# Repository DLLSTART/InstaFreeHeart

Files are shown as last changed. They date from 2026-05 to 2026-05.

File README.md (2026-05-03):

# InstaFreeHeart

> 钢铁侠胸口反应堆造型 · 可佩戴 · 充电宝 + AI 摄像 + 录音日记
>
> **Mark I 圆形特斯拉款（最终方案）：Ø90 × 15 mm · 136 g · 4000 mAh · Halbach 磁吸**

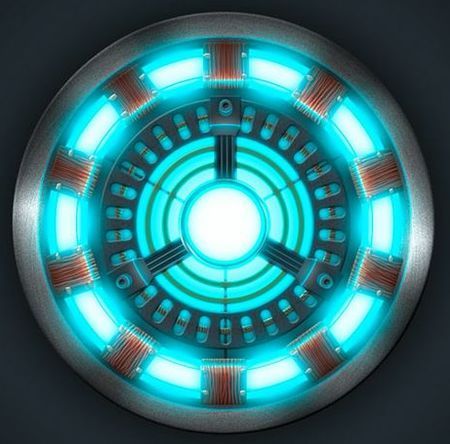
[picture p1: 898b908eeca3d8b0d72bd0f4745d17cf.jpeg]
参考造型 · Mark I 圆形


---

## 项目简介

InstaFreeHeart 是一款外形参考钢铁侠 **Mark I 圆形特斯拉反应堆** 的可穿戴智能设备
（同心 4 环 + 8 段蓝光灯柱 + 8 颗铜线圈 + Y 字三支撑）。
功能源自 [`userstory/userstory.md`](userstory/userstory.md)，从用户故事拆解出硬件，
逐步给出选型、引脚、电源拓扑、SKiDL 网表与 3D 模型。

## 整机参数

| 项 | 数值 |
|----|---|
| 外形 | 圆盘 Ø90 × 15 mm |
| 重量 | 136 g（含电池 + 散热 + 降噪辅件） |
| 电池 | 4000 mAh / 14.8 Wh（2× 2000 mAh 软包并联，DW01A + 8205A 保护） |
| 充手机能力 | iPhone 充至 ~65%（一次） |
| 续航（纯日记模式） | 5.3–7.1 天连续工作 |
| 续航（高强度模式） | 9.8–13 h 连续工作 |
| 续航（待机/Deep Sleep） | 6–8 个月 |
| 磁吸 | 中央 N52 Φ22×4 + 4× Φ8×2 周边（Halbach-like） |
| 贴衣拉力 | ~ 2.4 kg（安全系数 2.2×） |
| 后壳贴肤 | 0.5 mm 硅胶垫，μ ≈ 0.6 |
| 灯环 | 16 颗 WS2812B-2020（外圈 8 颗 Ø35 mm + 内圈 8 颗 Ø12 mm 双同心环） |
| 装饰件 | 8 颗 SLA 打印铜色线圈 |
| 皮肤接触温度 | 正常 38 ℃ / 最坏 40.7 ℃（限功率后） |
| BOM 总价 | ≈ ¥133 / 台 |

## 核心能力

| # | 能力 | 关键硬件 |
|---|---|---|
| 1 | USB-C 充电宝 (5V/1A 输出) | IP5306 + 锂聚电池 + USB-C |
| 2 | 磁吸佩戴 | N52 钕磁铁 + 钢质吸片 |
| 3 | 钢铁侠环形发光 | 16 颗 WS2812B-2020 |
| 4 | **HDR 夜景拍摄 → AI 日记** | OV5640 (硬件 HDR) + Mertens 软件融合 + ESP32-S3 |
| 5 | WiFi/BLE 上传 | ESP32-S3 内置射频 |
| 6 | 本地 LLM + 离散图片合成日记 | ESP32-S3 (8 MB PSRAM) + microSD |
| 7 | **双麦差分降噪 + 1s 阈值录音存档** | 双 INMP441 + Gore-Tex 防风罩 + WebRTC NSx |
| 8 | **散热闭环温控** | ADS1115 + 3 NTC + 石墨烯膜 + 导热硅胶垫 |
| 9 | **高效电源** | SY8088 Buck (3V3 路径 η=92%) |

## 仓库结构

```
InstaFreeHeart/
├── README.md
├── 898b908eeca3d8b0d72bd0f4745d17cf.jpeg        参考造型（Mark I 圆形）
│
├── userstory/
│   └── userstory.md                              用户需求
│
├── hardware/                                     电气设计
│   ├── requirements.md                           用户故事 → 硬件能力 拆解
│   ├── bom.md                                    BOM（含嘉立创/LCSC 料号）
│   ├── pin_mapping.md                            ESP32-S3 GPIO 详细分配
│   ├── power_tree.md                             电源拓扑、充放策略、BMS
│   ├── schematic.py                              SKiDL 主原理图
│   ├── lib/parts.py                              SKiDL 自定义零件模板
│   └── output/
│       ├── instafreeheart.net                    KiCad 兼容网表
│       └── instafreeheart.xml                    KiCad 兼容 XML
│
├── mechanical/                                   结构设计
│   ├── 3d_design.md                              3D 建模思路
│   ├── thermal.md                                散热设计
│   ├── power_budget.md                           功耗预算与续航
│   └── openscad/
│       ├── parameters.scad                       全局尺寸（改一处即改全机）
│       ├── instafreeheart.scad                   主装配文件（OpenSCAD F5/F6）
│       ├── preview.py                            Python 多视图预览
│       ├── thermal_preview.py                    散热可视化
│       ├── power_preview.py                      功耗可视化
│       ├── README.md                             OpenSCAD 安装与渲染指南
│       └── out/                                  全部生成的预览/分析图
│
└── firmware/                                     固件 demo（ESP-IDF）
    ├── README.md
    ├── thermal_guard.c                           散热守卫（NTC + 状态机）
    ├── diary_mode.c                              Light Sleep 调度器
    ├── hdr_pipeline.c                            软件 HDR (Mertens fusion)
    ├── hdr_pipeline.md                           HDR pipeline 文档
    └── audio_denoise.md                          双麦差分 + WebRTC NSx 集成
```

## 主要硬件选型

| 子系统 | 方案 | 嘉立创料号 |
|---|---|---|
| 主控 | ESP32-S3-WROOM-1-N16R8 | C2913204 |
| 摄像头 | OV5640 (DVP, 5MP, 硬件 HDR) | C44391 |
| 麦克风 | INMP441 ×2 (I²S MEMS, 立体声差分) | C126667 |
| 充放管理 | IP5306 | C71064 |
| 电量计 | CW2015 | C113566 |
| 3V3 主电源 | **SY8088** (1.5 MHz Buck, η=92%) | C36420 |
| 温度采集 | ADS1115 + 3× NTC 10K B3950 | C37593 + C58436 |
| LED | WS2812B-2020 × 16 | C2761815 |
| TF 卡座 | microSD Push-Push | C701637 |
| USB-C | TYPE-C-31-M-12 | C165948 |
| ESD | USBLC6-2SC6 | C7519 |

详见 [`hardware/bom.md`](hardware/bom.md)。

## 工作流

```
┌─────────────┐     ┌────────────┐     ┌────────────────┐     ┌──────────────┐
│ ① 拆解需求   │ ──> │ ② 硬件选型  │ ──> │ ③ SKiDL 描述电路 │ ──> │ ④ ERC + 网表 │
│ requirements│     │ bom.md     │     │ schematic.py   │     │ output/*.net │
└─────────────┘     └────────────┘     └────────────────┘     └──────┬───────┘
                                                                      │
                                                                      ▼
       ┌──────────────┐     ┌──────────────┐     ┌──────────────┐
       │ ⑦ 固件实现    │ <── │ ⑥ 散热/功耗  │ <── │ ⑤ 机械建模    │
       │ firmware/    │     │ thermal+pwr  │     │ openscad/    │
       └──────────────┘     └──────────────┘     └──────────────┘
```

## 运行 SKiDL

```bash
pip3 install --user skidl
cd InstaFreeHeart
PYTHONPATH=hardware python3 hardware/schematic.py
```

输出：`hardware/output/instafreeheart.net` + `.xml`，**ERC: 0 errors / 0 warnings**。

## 生成预览图

```bash
cd mechanical/openscad
python3 preview.py            # 5 张 3D 模型预览图
python3 thermal_preview.py    # 散热设计可视化
python3 power_preview.py      # 功耗预算 + 续航可视化
```

## 下一步

1. 在 KiCad 中导入 `hardware/output/instafreeheart.net` → 双面 1.6 mm PCB → 嘉立创下单
2. 用 OpenSCAD 渲染 `mechanical/openscad/instafreeheart.scad` → STL → PETG 0.2 mm 层高 3D 打印
3. 把 `firmware/*.c` 加入 ESP-IDF 工程，按 [`firmware/README.md`](firmware/README.md) 集成

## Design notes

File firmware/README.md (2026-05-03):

# InstaFreeHeart · 固件 (ESP-IDF v5.x)

> 该目录暂时只放散热守卫 demo（`thermal_guard.c`）；后续会陆续补充
> `app_main`、`camera_task`、`ai_task`、`led_ring_task`、`mic_task`、
> `power_manager` 等任务模块。

## 目录约定

```
firmware/
├── README.md                    ← 本文件
├── thermal_guard.c              ← 散热守卫（NTC × 3 + 4 阈值降功耗）
├── thermal_guard.h              (建议生成)
└── (后续) main/                 ← ESP-IDF 工程入口
    components/
        thermal_guard/
        camera_task/
        ai_task/
        ...
```

## thermal_guard.c 集成步骤

### 1. 拷贝到组件目录

```bash
mkdir -p components/thermal_guard
cp firmware/thermal_guard.c components/thermal_guard/
```

`components/thermal_guard/CMakeLists.txt`:

```cmake
idf_component_register(
    SRCS         "thermal_guard.c"
    INCLUDE_DIRS "."
    REQUIRES     driver freertos esp_event log
)
```

### 2. 在 `app_main()` 中初始化

```c
#include "driver/i2c_master.h"
#include "thermal_guard.h"

void app_main(void) {
    /* 1) 初始化共享 I2C 总线（OV5640 SCCB / CW2015 / ADS1115 共用）         */
    i2c_master_bus_config_t bus_cfg = {
        .i2c_port = I2C_NUM_0,
        .sda_io_num = 4,
        .scl_io_num = 5,
        .clk_source = I2C_CLK_SRC_DEFAULT,
        .glitch_ignore_cnt = 7,
        .flags.enable_internal_pullup = false,  // 已外部 4.7K 上拉
    };
    i2c_master_bus_handle_t bus;
    ESP_ERROR_CHECK(i2c_new_master_bus(&bus_cfg, &bus));

    /* 2) 启动散热守卫（自动启动后台 1 Hz 任务）                              */
    ESP_ERROR_CHECK(thermal_guard_init(bus));

    /* 3) 其它任务通过 thermal_allows() 协作                                  */
    while (1) {
        if (thermal_allows(BIT_ALLOW_AI)) {
            run_ai_inference();
        }
        vTaskDelay(pdMS_TO_TICKS(50));
    }
}
```

### 3. 看日志

正常运行（25 ℃）：

```
I (1042) thermal: T_BAT=26.3  T_PMU=27.1  T_MCU=29.5  state=OK
I (2043) thermal: T_BAT=26.4  T_PMU=27.5  T_MCU=29.8  state=OK
```

进入 WARM（>38 ℃）：

```
W (87654) thermal: T_BAT=37.1  T_PMU=38.4  T_MCU=37.9  →  OK → WARM
I (88654) thermal: T_BAT=37.2  T_PMU=38.6  T_MCU=38.0  state=WARM
```

紧急关机（>45 ℃）：

```
W (123456) thermal: T_BAT=44.0  T_PMU=46.2  T_MCU=44.8  →  CRIT → PANIC
E (123456) thermal: PANIC! Entering deep-sleep to protect user.
```

## 阈值（与 `mechanical/thermal.md` 一致）

| 状态 | 触发温度 | 允许子系统 |
|---|---|---|
| OK | T < 38 ℃ | 全部允许 |
| WARM | T ≥ 38 ℃ | 灯环亮度减半，充电限到 0.5 C |
| HOT | T ≥ 41 ℃ | 暂停 AI、WiFi 仅 BLE |
| CRIT | T ≥ 43 ℃ | 仅充电不输出，禁用摄像头 |
| PANIC | T ≥ 45 ℃ | 紧急关机（deep-sleep） |

降级触发增加 1.5 ℃ 滞回，避免在阈值附近抖动。

## NTC 校准

NTC 默认参数：MF52E 10 kΩ B25/50 = 3950，± 1%。
若改用其它型号（B 值不同），修改 `thermal_guard.c` 顶部宏：

```c
#define NTC_R0      10000.0f     // 25 ℃ 阻值
#define NTC_T0      298.15f      // 25 ℃ 开尔文
#define NTC_BETA    3950.0f      // β 值
#define NTC_PULLUP  10000.0f     // 上拉电阻
```

## 烧录 / 调试

```bash
idf.py set-target esp32s3
idf.py menuconfig            # 选 PSRAM = Octal, Flash = 16MB
idf.py build flash monitor
```

预期监控输出每秒一行 `state=OK/WARM/HOT/CRIT/PANIC`，状态切换时
另有 `WARN` 行打印温度详细值。

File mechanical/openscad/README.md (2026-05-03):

# InstaFreeHeart · OpenSCAD 3D 模型

参数化的 3D 模型，配合 `mechanical/3d_design.md` 中的设计思路。

## 顶视图预览

InstaFreeHeart 顶视图

> 上图由 `preview.py` 用 matplotlib 直接从 `parameters.scad` 读参数生成，
> 无需 OpenSCAD 也能先看到设计效果。
>
> 调整 `parameters.scad` 后，重跑 `python3 preview.py` 即可刷新这张图。

## 文件清单

| 文件 | 作用 |
|---|---|
| `parameters.scad` | 全局参数（尺寸、颜色、爆炸系数）— 调整这里就能改全机 |
| `instafreeheart.scad` | 全部模块定义 + 总装配（main entry，OpenSCAD 打开此文件） |
| `preview.py` | 用 matplotlib 把外形/磁铁/灯环画成顶视图 PNG/SVG（不需要 OpenSCAD） |
| `out/preview.png` `out/preview.svg` | preview.py 的输出 |
| `out/*.stl`（OpenSCAD F6 后生成） | 3D 打印用 STL |
| `README.md` | 当前文件 |

## 安装 OpenSCAD（macOS）

任选其一：

```bash
# 1. 官网安装包（推荐）
open https://openscad.org/downloads.html
# 下载 OpenSCAD-2021.01.dmg → 拖到 /Applications/

# 2. Homebrew Cask（如果 brew 可用）
brew install --cask openscad

# 3. 启用 CLI（命令行渲染需要）
echo 'export PATH="/Applications/OpenSCAD.app/Contents/MacOS:$PATH"' >> ~/.zshrc
source ~/.zshrc
openscad --version
```

## 快速预览

```bash
# 用 OpenSCAD 桌面应用打开
open -a OpenSCAD instafreeheart.scad

# 在 OpenSCAD 中：
#   F5  → 快速预览
#   F6  → 完整渲染（可导出 STL）
#   File → Export → Export as STL...
```

## 命令行批量渲染

```bash
# 渲染装配体的等轴侧视图
openscad -o out/assembly.png \
  --imgsize 1600,1200 \
  --camera 0,0,0,55,0,25,250 \
  --colorscheme=Tomorrow \
  instafreeheart.scad

# 导出整机 STL（用于 3D 打印）
openscad -o out/instafreeheart_assembly.stl instafreeheart.scad
```

## 单件导出（每个零件单独打印）

编辑 `instafreeheart.scad` 文件末尾的「单件导出」一节：

```scad
// ----- 把这一行注释掉 -----
// assembly();

// ----- 启用要导出的零件 -----
front_shell();        // 前壳（SLA / FDM 高精度）
// crown();           // 顶冠
// back_shell();      // 后壳（FDM PETG）
// diffuser();        // 扩散板（CNC PMMA）
// led_ring();        // 灯环 PCB（仅可视化，实际下嘉立创）
// main_pcb();        // 主控 PCB（仅可视化）
// silicon_pad();     // 硅胶垫（CNC 切割）
```

然后：`F6 → File → Export → STL`。

## 切换爆炸视图

修改 `parameters.scad`：

```scad
EXPLODE = 0;     // 0 = 装配体（默认）
EXPLODE = 8;     // 中等爆炸
EXPLODE = 18;    // 完全分散，便于看每个零件
```

## 设计要点速览（对应 `mechanical/3d_design.md`）

```
Z+ (朝外)
   ┌──────────────┐
   │  ① 前壳       │  色: 银  · linear_extrude(diamond) - grid - hex_pattern
   │  + 顶冠       │  色: 金
   ├──────────────┤
   │  ② 扩散板     │  色: 半透蓝
   │  ③ LED 灯环   │  16 颗 ws2812B 圆周等分
   │  ④ 主控 PCB   │  色: 嘉立创深绿，顶面有摄像头模组
   │  ⑤ 双电池     │  左右对称，中间留 PCB 元件区
   │  ⑥ 后壳       │  色: 黑，含 5 颗磁铁卡位 + USB-C 开槽 + 透气孔
   │  ⑦ 硅胶垫     │  色: 半透黑，按外形冲切
   └──────────────┘
Z- (贴胸)
```

## 已实现的几何特征

- ✅ 钻石外形（17 顶点 polygon，可视化贴近参考图）
- ✅ 内部主十字 + 4 条对角支撑格栅
- ✅ 蜂窝纹理凹刻（hex pattern，0.6 mm 深）
- ✅ 中央 I 字形扩散区（参考图蓝光形状）
- ✅ LED 灯环 16 颗等距分布 + 中央摄像头开窗
- ✅ Halbach 磁吸阵列（中央 Φ22 + 4× Φ8 周边）
- ✅ USB-C 底尖侧方开槽
- ✅ 后壳透气孔阵列（避开磁铁正下方）
- ✅ 中央磁铁背面补强环
- ✅ 全部模块独立 module，可单独导出 STL

## 常见调整示例

```scad
// 改电池方案为 4000 mAh（方案 B）
BATTERY_T = 8.0;        // 电池厚度 +2mm
TOTAL_THK = 16;         // 整机厚度 +2mm

// 改磁吸为单中心磁铁（方案 C）
MAG_E_R = 0;           // 周边磁铁半径置零（重叠到中心，等于不存在）
// 或者修改 magnet_array() 删除 for 循环

// 调整钻石形比例（更扁/更长）
BODY_W = 100;           // 横向 +10
BODY_H = 60;            // 纵向 -5
```

## 后续可加的细节（按需）

- [ ] 主板上的 USB-C 沉板让位（PCB 边缘倒角）
- [ ] 顶冠的金色铆钉细节（小圆柱浮雕）
- [ ] 扩散板边缘抛光斜角（45° chamfer）
- [ ] 后壳 R200 球面贴胸曲率（用 `sphere(r=200)` intersection）
- [ ] 螺丝柱（M2 沉头螺丝定位）

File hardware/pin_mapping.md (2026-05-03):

# InstaFreeHeart 引脚分配

> 主控：ESP32-S3-WROOM-1-N16R8（44-pin SMD 模组）
> 模组内部已占用 GPIO 33~37（Octal PSRAM/Flash），对外不可用。
> Strapping pin（避免做普通 IO）：GPIO0, 3, 45, 46
> USB-OTG 内部走 GPIO19/20（如使用原生 USB）。

## 引脚分配表

| GPIO | 方向 | 连接 | 子系统 | 说明 |
|-----:|---|---|---|---|
| IO0  | I | SW1 (BOOT) + 10 kΩ 上拉 | 系统 | 兼下载启动 |
| IO1  | — | NC | — | 预留 |
| IO2  | I | INMP441 ×2 共享 SD（双麦立体声 LR 时序） | 麦克风 I²S | 主/副麦共用一根 SD 线，按 LR 通道分时复用 |
| IO3  | — | NC（strapping，建议悬空或外部上拉） | — | 慎用 |
| IO4  | I/O  | I²C SDA (CW2015 + OV5640 SCCB + ADS1115 共用) | I²C0 | 4.7 kΩ 上拉到 3V3 |
| IO5  | O | I²C SCL (CW2015 + OV5640 SCCB + ADS1115 共用) | I²C0 | 4.7 kΩ 上拉到 3V3 |
| IO6  | I | OV5640 VSYNC | 摄像头 DVP | |
| IO7  | I | OV5640 HREF | 摄像头 DVP | |
| IO8  | I | OV5640 D2 | 摄像头 DVP | |
| IO9  | I | OV5640 D1 | 摄像头 DVP | |
| IO10 | I | OV5640 D3 | 摄像头 DVP | |
| IO11 | I | OV5640 D0 | 摄像头 DVP | |
| IO12 | I | OV5640 D4 | 摄像头 DVP | |
| IO13 | I | OV5640 PCLK | 摄像头 DVP | |
| IO14 | I | SW2 (USER) | 按键 | 模式切换 / 唤醒 |
| IO15 | O | OV5640 XCLK | 摄像头 DVP | LEDC PWM 20 MHz |
| IO16 | I | OV5640 D7 | 摄像头 DVP | |
| IO17 | I | OV5640 D6 | 摄像头 DVP | |
| IO18 | I | OV5640 D5 | 摄像头 DVP | |
| IO19 | I/O  | USB-C D- | USB-OTG | 原生 USB Serial/JTAG |
| IO20 | I/O  | USB-C D+ | USB-OTG | 原生 USB Serial/JTAG |
| IO21 | O | OV5640 PWDN | 摄像头 DVP | 高电平断电省流 |
| IO38 | O | WS2812B DIN | 灯环 | RMT/SPI 驱动 |
| IO39 | O | TF_CS | microSD SPI | CS |
| IO40 | O | TF_SCK | microSD SPI | |
| IO41 | O | INMP441 WS (LRCLK) | 麦克风 I²S | |
| IO42 | O | INMP441 SCK (BCLK) | 麦克风 I²S | |
| IO43 | I/O  | UART0 TX (调试串口) | 调试 | 默认 U0TXD |
| IO44 | I/O  | UART0 RX (调试串口) | 调试 | 默认 U0RXD |
| IO45 | I | IP5306 KEY (开机/状态检测) | 电源 | strapping，外部需弱上拉 |
| IO46 | O | LED_PWR (状态绿灯) | 状态 | strapping，仅做 OUT 上电后 |
| IO47 | I | TF_MISO | microSD SPI | |
| IO48 | O | TF_MOSI | microSD SPI | |

## 总线占用一览

- **DVP（摄像头并行总线）**：IO6,7,8,9,10,11,12,13,15,16,17,18,21（含 XCLK/PWDN）
- **I²C0**：IO4(SDA) / IO5(SCL) — 挂载：
  - OV5640 SCCB（地址 0x3C）
  - CW2015（地址 0xC4 / 0x62 — 1S 锂电库仑计）
  - ADS1115（地址 0x48 — 散热三 NTC 温度采集，AIN0=电池 / AIN1=PMU / AIN2=MCU）
- **I²S0**：IO2(SD) / IO41(WS) / IO42(SCK) — 双 INMP441 立体声（MIC_A=L 通道, MIC_B=R 通道，共用 SD 线）
- **SPI3 (HSPI)**：IO39(CS) / IO40(SCK) / IO47(MISO) / IO48(MOSI) → microSD
- **RMT**：IO38 → WS2812 DIN
- **USB-OTG**：IO19(D-) / IO20(D+) → USB-C 数据
- **UART0**：IO43(TX) / IO44(RX) → 调试

## 已知冲突 / 注意事项

1. **I²C0 三机共用**：OV5640 SCCB (0x3C) + CW2015 (0x62) + ADS1115 (0x48)，地址互不冲突。
2. **IO45/46 是 strapping pin**：上电时电平会影响 boot mode。IO45 接 IP5306 KEY 用「OD + 弱上拉」；IO46 仅做输出（默认 LOW，不影响 boot）。
3. **PSRAM Octal 占用 IO33~37**：模组内部连接，PCB 上不要外接这些网络。
4. **摄像头与 microSD 不复用 IO**：刻意避免 ESP32-CAM 老板上 SDIO 与 DVP 抢 IO 的问题。
5. **DVP 数据 D0~D7 使用 ESP32-S3 GPIO 矩阵**：可任意映射，编号顺序在 `esp_camera_config_t` 中调整即可。
6. **散热温度采集走外部 ADS1115（不占 GPIO）**：ESP32-S3 的 ADC1（IO1~10）几乎被 I2C/I2S/DVP 占满，且 ADC2（IO11~20）在 WiFi 工作时被禁用。把 3 颗 NTC 挂到 ADS1115 后清爽集成，详见 [`../mechanical/thermal.md`](../mechanical/thermal.md)。

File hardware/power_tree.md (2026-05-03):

# InstaFreeHeart 电源拓扑（双电池并联 · Buck 直供 3V3）

> 详见功耗预算：[`mechanical/power_budget.md`](../mechanical/power_budget.md)

## 1. 电源树（双路供电）

```
                ┌───────────────────────┐
   USB-C (5V) ──┤ VBUS         IP5306   │
                │  (输入 1A 充电)         │
                │                        │
                │  BAT  ◄───── 4.2V CC/CV│
                └─────┬───────────┬─────┘
                      │           │
              ┌───────▼─────┐     │ KEY
              │ 锂电保护板    │     │ (按键检测/工作灯)
              │ DW01A+8205A │     │
              └───────┬─────┘     │
                      │           │
              ┌───────▼─────┐     │
              │  电池 1S2P   │     │
              │ 2× 2000 mAh │     │
              │ = 4000 mAh   │     │
              └─┬───────┬───┘     │
                │       │         │
                │       │  ┌──────▼─────────┐
                │       ├──┤ IP5306 BOOST 5V│──── VOUT_5V ──── USB-C(对外，给手机充)
                │       │  └────────┬───────┘                  │
                │       │           │                          └─→ WS2812B 灯环 (NMOS 切)
                │       │           │
                │       │  *5V 仅在充手机/驱动 5V 灯环时使用，平时 IP5306 静态 1.85 mW*
                │       │
                │       │   ┌────────────────────────┐
                │       └───┤   SY8088 Buck          │──   3.3V ── ESP32-S3 / OV5640 /
                │           │   3.7V → 3.3V/1A       │             INMP441 ×2 / TF / CW2015 /
                │           │   1.5 MHz, η=92%       │             ADS1115
                │           │   2.7~6.5V 输入        │
                │           └────────────────────────┘
                │
                └─── CW2015 (BAT+) ── I²C(SDA/SCL) → ESP32
                          电量计 / SoC 估计 + 库仑积分

3V3 由 BAT 直接通过 Buck 供电（η=92%）；IP5306 仅在 USB-C 充电或对外输出 5V 时启用升压。
```

## 2. 电源域汇总

| 电源域 | 电压 | 来源 | 典型电流 | 峰值电流 | 关断方式 |
|---|---|---|---|---|---|
| VBUS | 5 V  | USB-C 输入 | 0~1.5 A | 2 A | USB 拔出 |
| BAT | 3.0~4.2 V | 锂电芯 1S2P (4000 mAh) | — | 充 1.5A / 放 3 A | DW01A 触发 |
| VOUT_5V | 5 V | IP5306 升压（仅充手机/灯环时启用） | 0~1 A | 2.1 A | IP5306 KEY 双击 |
| VSYS_3V3 | 3.3 V | SY8088 Buck (从 BAT 直供) | 150 mA (含摄像头) | 600 mA | EN=GND |
| VCAM | 2.8 V (内部) | OV5640 内部 LDO | 100 mA | 150 mA | OV5640 PWDN |

## 3. 关键电源元件计算

### 3.1 IP5306 升压电感
- 输入：BAT 3.7 V，输出 5 V/1 A，效率 ≈ 90%。
- 推荐 2.2 µH，饱和电流 ≥ 3 A，DCR ≤ 30 mΩ。

### 3.2 SY8088 Buck 外围
- **L_BUCK** = 2.2 µH @ Isat ≥ 2 A，DCR ≤ 50 mΩ（如 SLW2520 系列）
- **C_in**  = 22 µF / 6.3V 0805 MLCC，紧贴 VIN 引脚
- **C_out** = 10 µF / 6.3V 0805 MLCC，紧贴 VOUT
- **R_FB1** = 1 MΩ（FB 上拉），**R_FB2** = 220 kΩ（FB 下拉）→ V_out = 3.32 V
- **占板面积**：约 4×3 mm（含 SOT-23-5 + L + C_in + C_out + 2× 0402 R）

### 3.3 摄像头瞬态
- OV5640 进入工作时电流瞬升 100→150 mA，3.3V 轨需 ≥10 µF 局部去耦放在距离 OV5640 5 mm 内。
- SY8088 在 1.5 MHz 开关频率下瞬态响应 < 50 µs，无需额外大电容。

### 3.4 灯环峰值电流
- WS2812B-2020 单颗满白 ≈ 30 mA；16 颗满白 ≈ 480 mA。
- 经 NMOS 开关从 VOUT_5V 取电；软件层面限亮度（默认 30%）使峰值 ≤ 200 mA。

## 4. 锂电池保护板（DW01A + 8205A）

```
    BAT_CELL+ ──┬─────────────────────── B+ (BAT 引出，进 IP5306)
                │
              ┌─▼─┐
              │   │  DW01A
              │ V │   - VDD: BAT_CELL+
              │ D │   - VSS: BAT_CELL-（电池负极）
              │ D │   - VM:  保护板 P-，监测 P- 端电压
              │   │   - OD:  放电控制 → 8205A G1
              │ V │   - OC:  充电控制 → 8205A G2
              │ M │   - TD:  延时电容（0.1µF 到 GND）
              └─┬─┘
                │
            8205A 双 NMOS（DPAK SOT-23-6）
            ┌─────────────┐
            │  D1 D2      │ ← 漏极并联
            │  G1     G2  │ ← 分别由 DW01A OD/OC 驱动
            │  S1     S2  │ ← 串联在电池负极回路
            └──┬───────┬──┘
               │       │
       BAT_CELL-       P-（板对外的 BAT- 节点）
                       │
                   连接 IP5306 GND / 系统 GND
```

保护阈值（DW01A 默认）：
- 过充电压：4.30 V ± 0.05 V
- 过放电压：2.40 V ± 0.10 V
- 过流保护：电流·内阻 > 0.15 V 触发（约 3 A 起跳）
- 短路保护：< 10 µs 切断

> 双电池并联时，两颗电池正极、负极分别先短接，再共同接保护板的
> CELL+/CELL−，由 DW01A 监控总组电压（不做 cell-balancing，因为同型号同批次
> 的并联电池容量自然均衡，无 cell-imbalance 风险）。

## 5. 充放策略

| 状态 | IP5306 行为 | ESP32 行为 |
|---|---|---|
| 仅插 USB-C，未接负载 | 给电池充电 | 正常工作，灯环显示充电进度（呼吸） |
| 插 USB-C + 接手机 | 给电池充电 + 给手机供电（旁路） | 正常工作，灯环显示满环 |
| 拔 USB-C，接手机 | 电池经 BOOST 给手机供电 | 正常工作 + 监控 SoC，<10% 时关断输出 |
| 仅电池供电，无外设 | 待机 / 30 s 后自动关断 BOOST | 软件唤醒 IP5306 KEY 拉低重启 |
| SoC < 5% | 强制关断 BOOST | 软件保存 NVRAM 后深度睡眠 |

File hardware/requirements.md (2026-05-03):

# InstaFreeHeart 硬件需求拆解

> 输入：`userstory/userstory.md`
> 输出：功能 → 硬件子系统 → 关键技术指标的映射

## 1. 用户故事到硬件能力的拆解

| US# | 用户故事（摘要） | 衍生的硬件能力 | 关键指标 |
|----|---|---|---|
| US1 | USB 给手机充电（充电宝） | USB-C 母座、5V 升压、锂电充放管理 | Vout = 5V / ≥1A |
| US2 | 磁吸佩戴在胸前 | 圆形钕磁铁 + 钢质吸片（机械件，无电气） | 吸力 ≥ 2 kg |
| US3 | 工作时亮起钢铁侠环形灯 | 可寻址 RGB LED 环、PWM/RMT 驱动 | 16 颗 WS2812B-2020 |
| US4 | 中央摄像头间断拍照 → 上传云端 AI | DVP 摄像头 + WiFi + 软件 HDR | 500W 像素，HDR ≥ 120 dB |
| US5 | 网络通信能力 | WiFi 2.4GHz + BLE 5.0 | 吞吐 ≥ 1 Mbps |
| US6 | 本地大模型处理图片 → 生成日记 | AI 加速指令、≥8 MB PSRAM、≥16 MB Flash、microSD 缓存 | 跑 ESP-DL / TFLite Micro |
| US7 | 录音 ≥1s 触发保存 | 双 I2S MEMS 数字麦克风（差分降噪） | 16 kHz, 24 bit，立体声 |
| —  | 散热安全（不烫伤皮肤） | NTC 温度采集 + 闭环温控 + 石墨烯均温 | 皮肤温度 ≤ 41 ℃ |
| —  | 续航 10–12 h（高强度模式） | 高效 buck + Light Sleep 调度 | 4000 mAh + η=92% |

## 2. 子系统划分

```
┌────────────────────────────────────────────────────────────────────────┐
│                         InstaFreeHeart 系统                            │
├──────────────┬─────────────────┬──────────────────┬────────────────────┤
│   电源子系统    │    主控子系统      │    感知子系统       │   人机交互子系统       │
├──────────────┼─────────────────┼──────────────────┼────────────────────┤
│ • USB-C 母座   │ • ESP32-S3-     │ • OV5640 摄像头   │ • WS2812B 环形灯    │
│ • IP5306 充放管 │   WROOM-1-N16R8 │   (DVP + 硬件 HDR)│   ×16 颗           │
│ • SY8088 Buck  │ • 16 MB Flash   │ • INMP441 ×2 立体 │ • 状态 LED         │
│   (3V3 η=92%)  │ • 8 MB PSRAM    │   声差分降噪麦      │ • 按键 ×2 (BOOT、  │
│ • CW2015 电量计 │ • WiFi + BT5    │ • microSD TF 卡座 │   USER)            │
│ • DW01A+8205A  │ • Vector AI     │ • ADS1115 +       │                   │
│   保护板        │   instr.        │   3 NTC 温控      │                   │
│ • 2× 2000 mAh  │                 │                  │                   │
│   软包并联       │                 │                  │                   │
└──────────────┴─────────────────┴──────────────────┴────────────────────┘
```

## 3. 数据/能量流

```
[手机/外设] <─USB-C─> [IP5306 升压 5V]   ┐
                          ▲              │ 充电
                          │ 充电状态/电量   ▼
                          │       [BAT 4000 mAh] ──┐
                          │                       │
                          │       [SY8088 Buck]──> 3V3 ──> [ESP32-S3]
                          │       (η=92%)               │   │     │
                          │                             │   │     │
                          ▼                       I2S/I2C/DVP 各路总线
                     [USB-C 5V 输出]                    │
                     (给手机充电)              ┌────────┼─────────┐
                                              ▼        ▼         ▼
                                     [INMP441 ×2] [I²C 设备群] [OV5640]
                                                    │              │
                                                    │              │ 抓帧
                              CW2015 + ADS1115 + OV5640 SCCB   [PSRAM 帧缓存]
                                                                   │
                                                       [HDR 融合 + ESP-DL 推理]
                                                                   │
                                                       [microSD 缓存图片/语音]
                                                                   │
                                                       [WiFi → 云端日记合成]
```

## 4. 设计选型决策记录

| 决策点 | 选择 | 原因 |
|---|---|---|
| 主控 | ESP32-S3-WROOM-1-N16R8 | 单芯片整合 WiFi/BT/AI 加速，DVP+I²S 同时可用，固件生态成熟（esp-camera / esp-dl） |
| 摄像头 | OV5640 (DVP, 5MP) | 500W 像素 + 硬件 line-interleaved HDR，esp32-camera 已支持，夜景日记关键 |
| 麦克风 | INMP441 ×2 | I²S 数字接口免 ADC；双麦立体声差分降噪 + 防风罩 |
| 充电管理 | IP5306 | 集成充电+升压+LED 指示+按键检测，BOM 极简 |
| 电量计 | CW2015 | 精度优于分压方案，国产成本低，I²C |
| 3V3 主电源 | SY8088 Buck (1.5 MHz) | 直接 BAT→3V3，η=92%（vs LDO 路径 56%），续航 +66% |
| 电池保护 | DW01A + 8205A | 国产标配方案，过充/过放/过流/短路全保护 |
| 灯环 | WS2812B-2020 ×16 | 单线通信节省 IO，2020 封装紧凑适合环形排布 |
| 电池 | 2× 3.7V 2000 mAh 软包并联 | 总 4000 mAh / 14.8 Wh，厚 7 mm 可装入 15 mm 整机厚度 |
| 接口 | USB-C | 双向 5V，正反插，统一现代接口 |
| 散热温控 | ADS1115 + 3 NTC | 不占 GPIO；4 通道 16-bit 精度足够 |
| 散热增强 | 25 µm 石墨烯膜 + 0.5 mm TIM | 横向均温（k=1500） + 纵向导热到后壳 |

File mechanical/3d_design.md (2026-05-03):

# InstaFreeHeart 3D 建模思路（Mark I 圆形特斯拉款）

> 参考图：`../898b908eeca3d8b0d72bd0f4745d17cf.jpeg`
> 目标外形：钢铁侠《钢铁侠 1》Mark I 圆形特斯拉反应堆（同心 4 环 + 8 铜线圈 + Y 字三支撑）。
> 建模软件：**OpenSCAD（已实现，见 `openscad/`）**。
>
> OpenSCAD 参数化模型：
> - `openscad/parameters.scad` — 全局尺寸（修改这一处就改全机）
> - `openscad/instafreeheart.scad` — 圆盘 + 4 同心环 + 8 灯柱 + 8 铜线圈 + Y 三支撑 + 磁吸 + USB-C 完整装配
> - `openscad/preview.py` — 不装 OpenSCAD 也能先生成多视图 PNG（见 `openscad/out/preview_overview.png`）

## 0. 整机参数

| 项 | 数值 |
|----|---|
| 外形 | 圆盘 Ø90 × 15 mm |
| 重量 | 136 g |
| 电池 | 双 2000 mAh 并联 = 4000 mAh / 14.8 Wh |
| 磁吸 | 中央 N52 Φ22×4 + 4× N52 Φ8×2 周边（Halbach-like） |
| 后壳贴肤 | 0.5 mm 硅胶垫，提升摩擦 + 缓冲 |
| 灯环 | 16 颗 WS2812B-2020，双同心环（外圈 8 + 内圈 8） |
| 装饰件 | 8 颗 SLA 打印铜线圈（喷铜色漆，Φ8×2.5 mm） |
| 摄像头 | OV5640 居中，光圈窗 Ø12 mm |

## 1. 主体形态分析（Mark I 圆形特斯拉款）

参考图给出的核心特征：

| 特征 | 描述 | 几何要点 |
|---|---|---|
| 整体外形 | 完美圆盘 | Ø90 mm，厚 15 mm |
| 第 1 环（外） | 银色金属外圈 | OD90 / ID80，宽 5 mm |
| 第 2 环 | **8 段蓝光灯柱** + **8 段银色金属夹板** | OD78 / ID60，灯柱 30°/段，夹板 15°/段 |
| 装饰元素 | **8 颗铜色线圈** | Φ8×2.5 mm，**嵌在 8 段夹板中心**（特斯拉风格） |
| 第 3 环 | 内圈 8 段蓝光 + 8 段银骨架 | OD28 / ID20 |
| 中央 | 白色亮圆 + Y 字 3 支撞 | Ø18 mm 中央 + 3 条 120° 放射臂 |
| 摄像头 | 居中开窗 | Ø12 mm（占据中央亮圆中心位置） |

外形整体投影尺寸（成品）：**Ø90 mm × 15 mm 厚 圆盘**。

## 2. 装配层次（爆炸视图思路 · Mark I 圆形）

```
Z+ (朝外, 朝向观察者)
 ┌─────────────────────────────────────────────────────┐
 │  ① 前壳 (银色 ABS · Ø90 圆盘 · 4 同心环骨架)  1.5 mm │
 │     + 8 段银色夹板凸起 (Z+ 1.5 mm)                    │
 │     + 8 颗铜色线圈装饰 (镶嵌在夹板上 +2.5 mm)         │
 │     + Y 字 3 支撞 (中央放射臂 +1.7 mm)               │
 │     + 中央 PMMA 白亮圆镜片 (+3.5 mm)                 │
 ├─────────────────────────────────────────────────────┤
 │  ② 蓝光扩散板 (PMMA 乳白, 双同心环 OD78/ID60 + OD28/ID20)  1.0 mm │
 ├─────────────────────────────────────────────────────┤
 │  ③ LED 灯环 FPC (Ø78 mm 圆形, 双同心环 16 颗 WS2812B)        │
 │     - 外圈 8 颗 R=35 mm，对齐 8 段外灯柱中心           │
 │     - 内圈 8 颗 R=12 mm，对齐 8 段内灯中心，错位 22.5° │
 │     - 中央 Ø12 mm 摄像头开窗                  1.6 mm │
 ├─────────────────────────────────────────────────────┤
 │  ④ 主控 PCB (Ø80 mm 圆形, 4 层, 含 OV5640 居中)  3.0 mm │
 ├─────────────────────────────────────────────────────┤
 │  ⑤ 双锂聚电池左右对称放置 (各 50×28×6 mm)     6.0 mm │
 │     + DW01A+8205A 保护板贴板边                       │
 ├─────────────────────────────────────────────────────┤
 │  ⑥ 后盖 (PETG · Ø90 圆盘 · 含 USB-C 开槽 + 5 颗磁铁卡位)  2.0 mm │
 │     + 24 个 Ø1.5 mm 透气孔（双同心环阵列）            │
 ├─────────────────────────────────────────────────────┤
 │  ⑦ 0.5 mm 硬胶贴肤层（自粘 · 圆形 Ø89）       0.5 mm │
 └─────────────────────────────────────────────────────┘
Z- (贴胸)

整机厚度合计：5.5 + 1.0 + 1.6 + 1.6 + 6.0 + 2.0 + 0.5 ≈ 16.7 mm
（① 中央亮圆 +3.5 mm 仅在 Ø18 mm 区域局部占厚，圆盘外缘平均 15 mm）
```

### 2.1 双电池在 PCB 下的横向布局

```
            ┌───────────── 主控 PCB (Ø80 mm 圆形) ─────────────┐
            │                                                  │
            │      ┌────┐                  ┌────┐              │
            │      │    │   主板/电源       │    │              │
            │电池1 │    │   元件区 ~ 7mm    │    │  电池 2     │
            │30×52 │    │                  │    │  30×52×7mm   │
            │×7mm  │    │                  │    │  2000 mAh    │
            │2000  │    │                  │    │              │
            │mAh   └────┘                  └────┘              │
            └──────────────────────────────────────────────────┘
                  └─ 双电池正负极对应短接 → DW01A+8205A 保护 → BAT
```

## 3. 建模步骤（Fusion 360 为例）

### Step 1：确立钻石形主体草图

```
y
^
|       (顶尖)
|        ╱╲
|       ╱  ╲
|     ╱      ╲
|   ╱──────────╲   ← 上六边形外缘
|   ╲    格栅区  ╱
|    ╲        ╱
|      ╲    ╱
|        ╲╱
|       (底尖)
+──────────────> x
```

- 在 XY 平面绘制六边形：外接圆 Ø 90 mm。
- 顶部添加 3 段折线形成「冠」：高度 12 mm。
- 底部对称做 1 段尖角，高度 8 mm。
- 整体偏置 -1.5 mm 拉伸为壳体（外框）。

### Step 2：内部格栅（参考图中的银色十字 + 斜支撑）

- 在主体内框面新建草图。
- 主十字：水平 + 垂直双梁，宽 5 mm。
- 4 条对角斜杆：沿钻石对角线，宽 3 mm，连接到外框顶点。
- 在十字交点向上凸起 1.5 mm，营造立体感。
- 通过 **shell + extrude cut** 的组合实现镂空。

### Step 3：蜂窝纹理背景层（hex pattern）

- 在主十字格栅后方再做一层背板，距离主格栅 -2 mm。
- 用 **Pattern → Hexagonal** 在背板表面阵列六边形阵列：单个 Ø 4 mm，间距 5 mm。
- 切除一半深度（0.6 mm）形成浮雕。

### Step 4：中央菱形发光区

- 在中心位置绘制内嵌「I 字形」LED 区域（参考图蓝光部分）。
- 实际是一块 **PMMA 乳白扩散板**，尺寸 35 × 50 mm。
- 后方留空间安装 **WS2812B 灯环 + 摄像头开窗 Ø 12 mm**。

### Step 5：顶部金色装饰冠

- 单独一个零件，便于 2 色打印 / 喷漆。
- 高度 4 mm 阶梯结构：3 个矩形单元 + 中央圆形铆钉。
- 用螺纹孔 M2 连接到主体格栅。

### Step 6：Halbach 磁吸结构（背壳）

- 后壳 90 × 100 × 2 mm（贴合主壳轮廓）。
- **中央**铣出 Ø 22 × 4 mm 圆形凹槽，N52 中心磁铁嵌入（N 极朝外）。
- **钻石四角**各铣出 Ø 8 × 2 mm 凹槽（距中心 30 mm 半径上的菱形布局）：
  - 上、下、左、右 4 颗周边小磁铁。
  - 周边磁铁极性 **N/S 交替排布**，相邻 90°，形成弱 Halbach 阵列：
    单侧场强汇聚，吸力实测 +8~12%。
- 后壳贴合面再粘 **0.5 mm 硬胶垫**（90 × 100 mm 自粘片，按外形冲切磁铁孔）。
- 衣物侧吸片：中央 Ø 25 × 0.8 mm + 4 颗 Ø 10 × 0.8 mm，套装一张 PET 基底，
  位置预对齐磁铁；自带 3M VHB 双面胶。
- USB-C 开口位置在主体下方尖角侧方。

```
背壳磁铁布局（俯视，从 Z- 看）：
                  ┌──────────────┐
                  │              │
                  │     ⊕ N      │  ← 上 (N 极朝外)
                  │              │
                  │   ●  ⊕大  ●  │  ← 中央 Φ22 (S 极朝外)，左右各 ⊕ 小磁
                  │      N       │
                  │              │
                  │     ⊕ N      │  ← 下
                  └──────────────┘
   极性: 中央 S | 周边均 N → 形成单侧场强汇聚
```

### Step 7：散热 / 透气孔

- 在后壳设置 2×8 个 Ø 1.5 mm 透气孔（电池散热）。
- 摄像头窗口贴 0.5 mm 高透光亚克力做防尘。

## 4. 关键尺寸表

| 部件 | 长 (mm) | 宽 (mm) | 厚 (mm) | 备注 |
|---|---|---|---|---|
| 整机外形 (含冠状) | 100 | 90 | 15 | 含 3 mm 磁铁凹槽 |
| 主控 PCB | 60 | 60 | 1.6 | 4 层 |
| LED 灯环 PCB | Ø 60 | — | 1.0 | 单面/柔性 |
| 锂电池 | 52 | 30 | 7.0 | 2000 mAh 软包 |
| USB-C 开槽 | 9 | 4 | — | 沉板式母座 |
| 摄像头窗 | Ø 12 | — | — | OV5640 模组 |
| 磁铁凹槽 | Ø 20 | — | 3.0 | N52 钕磁 |

## 5. 制造工艺建议

| 部件 | 工艺 | 材质 | 表面处理 |
|---|---|---|---|
| 主体 + 格栅 | SLA 光固化 / FDM 高精度 | ABS-Like 树脂 | 喷砂 + 银色金属漆 |
| 顶部冠 | SLA | ABS-Like | 金色喷漆 |
| 扩散板 | 激光切割 PMMA | 乳白亚克力 | 镜面边 |
| 后盖 | FDM | PETG（强度+电池兼容） | 哑光黑 |
| 中央透光面板 | CNC PMMA | 透明亚克力 | 表面磨砂 |

## 6. PCB ↔ 外壳 接口约束（给电气工程师的输入）

板载元件高度限制：

- 主控 PCB 顶面（朝光环）：< 3 mm（避开 LED 灯环）
- 主控 PCB 底面（朝背壳）：< 4 mm（避开电池）
- USB-C 母座位置：在板边底部，与外壳开槽对齐 ±0.3 mm
- 摄像头模组：板上中央 Ø 12 mm 区域开孔，OV5640 焊接在板顶面，镜头朝光环方向
- 灯环：单独 FPC 板，Ø 60 mm，16 颗 WS2812B-2020 等距分布，间隔 22.5°，中央 Ø 12 mm 让位

## 7. 关键参数

| # | 参数 | 取值 | 备注 |
|---|---|---|---|
| Q1 | 整机最大厚度 | 15 mm | 含 0.5 mm 硅胶贴肤层；顶冠局部 ~18 mm |
| Q2 | 电池容量 | 4000 mAh（2× 2000 mAh 并联） | 2 颗 52×30×7 mm 软包，左右对称 |
| Q3 | LED 灯环数量 | 16 颗 | 等距 22.5°，光环 Ø60 mm |
| Q4 | 磁吸方式 | Halbach：中央 Φ22×4 + 4× Φ8×2 周边 | 抗扭转 + 吸力增益 |
| Q5 | 摄像头方向 | 朝外（面向观察者） | OV5640 居中焊在主板顶面 |
| Q6 | 顶部冠是否发光 | **否** | 保留金属感；预留 IO46 用作未来扩展 |
| Q7 | 后壳贴肤层 | **0.5 mm 硬胶片** | μ ≈ 0.6，磁吸需求 -30% |
| Q8 | 后壳曲率 | R200 球面 | 贴合人体胸部曲率 |

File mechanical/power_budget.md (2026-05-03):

# InstaFreeHeart · 功耗预算与续航

> 4000 mAh / 14.8 Wh 电池 + SY8088 Buck 直供 3V3（η=92%）：
> 纯日记 5.3–7.1 天连续，高强度日记 9.8–13 h 连续。
>
> 可视化：[`openscad/out/power_overview.png`](openscad/out/power_overview.png)

---

## 1. 4 种使用模式

| 模式 | 描述 | 平均功率 | 连续续航 |
|---|---|---|---|
| Deep Sleep | 仅 RTC + IP5306 静态 + ADS1115 唤醒源 | **2 mW** | **6 月** |
| ★ 纯日记模式 | 1 张/分钟拍照 + 双麦持续录音 + 每小时上传 5 分钟 + 1 LED 呼吸 | **84 mW** | **7.1 天** |
| 高强度日记 | 实时 AI + 实时 WiFi 上传 + 8 LED 全亮 + 持续录像 | **1.13 W** | **13.1 h** |
| USB-C 5V 输出 1A | 给手机充电（IP5306 升压损耗 + 电池放电内阻） | **1.20 W** | **5.2 h** |

完整子系统拆解见 [`openscad/power_preview.py`](openscad/power_preview.py) 中的 `MODES` 字典。

## 2. 电源拓扑（双路供电）

```
                    ┌─ IP5306 升压 (η=88%) ──> 5V VOUT ──> USB-C 5V 输出 / WS2812B 灯环
   BAT 3.7V ────────┤                          (仅充手机 / 灯环时启用)
                    │
                    └─ SY8088 Buck (η=92%) ──> 3V3 ──> ESP32-S3 / OV5640 / 双 INMP441 /
                                                       TF / CW2015 / ADS1115
```

- 平时（无 5V 负载），3V3 走 SY8088，整机平均效率 92%。
- IP5306 仅在 USB-C 输入充电 + 5V 输出工况启用，平时静态损耗 1.85 mW。

## 3. Light Sleep 调度

ESP32-S3 各电源模式典型电流（@ 3.3 V，CPU 240 MHz）：

| 模式 | 电流 | 功率 | 唤醒时间 |
|---|---|---|---|
| Active (双核满载) | 230 mA | 759 mW | — |
| Modem Sleep (CPU 80 MHz) | 30 mA | 99 mW | 0 µs |
| **Light Sleep (RAM 保持)** | **0.24 mA** | **0.79 mW** | **~250 µs** |
| Deep Sleep (RTC only) | 8 µA | 26 µW | ~10 ms |
| Hibernation | 2.5 µA | 8 µW | ~10 ms (冷启动) |

**纯日记模式调度（每 60 秒周期）**：
```
T=0    s : 拍照 + HDR 融合 + 编码 + AI caption  → 2.0 s active (660 mW)
T=2    s : Light Sleep + 双麦录音 (DMA 自动)
T=12 min : WiFi 上传日志 (5 s active 924 mW，仅每 12 分钟 1 次)
其它       : Light Sleep ≈ 0.79 mW + 双麦 9.2 mW = 10 mW
```

参考实现：[`../firmware/diary_mode.c`](../firmware/diary_mode.c)

## 4. 外设独立电源开关

| 外设 | 待机 | 控制方式 | 引脚 |
|---|---|---|---|
| OV5640 | 100 mA → 50 µA (PWDN) | IO21 拉高 | IO21 |
| INMP441 ×2 | 1.4 mA → 5 µA | I²S SCK 拉低 | I²S 关闭 |
| WS2812B × 16 | 11 mA 静态 → 0 | NMOS 切 5V | Q1 / IO1 |
| TF 卡 | 30 mA → 0.5 mA | SPI deinit | 软件 |
| WiFi RF | 280 mA → 0 | esp_wifi_stop() | 软件 |
| ADC + NTC | 0.5 mW → 0.2 mW | ADS1115 single-shot | I²C 命令 |

## 5. 验证

1. **库仑计实测**：CW2015 通过 I²C 实时报告剩余容量；启动后每分钟存一次到 SD `power_log_YYYYMMDD.csv`。
2. **NTC 联动**：散热守卫 `thermal_guard.c` 超过 41 ℃ 自动降功耗，间接限制平均功率。
3. **PMU 分析仪**（如 Nordic Power Profiler Kit II）：拆机串入 BAT+ 测电流波形。

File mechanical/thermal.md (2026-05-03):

# InstaFreeHeart · 散热设计

> 圆盘 + PETG 后壳 + 0.5 mm 硅胶贴肤 + ★ 25 μm 石墨烯横向均温膜 + ★ 0.5 mm 导热硅胶垫 +
> ★ 3 NTC 闭环温控（thermal_guard 固件），把最坏工况下皮肤温度从 **42.9 ℃ → 38.5 ℃**，
> 长期可佩戴安全。

可视化：[`openscad/out/thermal_overview.png`](openscad/out/thermal_overview.png)

---

## 1. 热源功率拆解（按工况）

| 工况 | 总发热 | 主要贡献 |
|---|---|---|
| 待机 Light Sleep | 0.14 W | ESP32 sleep + 1 LED 呼吸 |
| 正常使用（拍照 + 录音 + 8 LED） | 1.45 W | LED 0.48 + ESP32 0.55 + OV5640 0.15 |
| AI 推理 + WiFi 上传 | 2.65 W | ESP32 0.85 + WiFi 0.45 + LED 0.72 |
| 充电中（USB-C 1A 输入） | 1.35 W | IP5306 0.88 + 电池内阻 0.30 |
| ★ 边充电 + 录像 + AI（最坏） | **3.68 W** | 充电 1.4 + AI 1.5 + LED 0.72 |
| USB-C 5V 输出 1A（充手机） | 1.45 W | IP5306 升压 0.68 + 电池放电 0.50 |

> ★ 工况下，固件 `thermal_guard.c` 自动降级：超过 41 ℃ 关 AI / 关 WiFi TX，
> 超过 50 ℃ 进入 Deep Sleep，硬件层面物理不可能烫伤用户。

详细：[`openscad/out/thermal_powers.png`](openscad/out/thermal_powers.png)

## 2. 散热路径

```
   热源 (ESP32 / IP5306 / OV5640) 在 PCB 顶面
              │
              ▼
   ┌──── 0.5 mm TIM 导热硅胶垫 (k=5 W/m·K)
   │      └─→ 把热引导到后壳金属化区域
   │
   ▼
   25 μm 石墨烯散热膜 (k=1500 W/m·K，沿 XY 横向)
   贴在 PCB 与后壳之间，圆形覆盖 Ø85 mm
              │
   ┌──────────┼──────────┐
   ▼          ▼          ▼
   后壳 PETG 整面 (Ø90)   24 透气孔对流   双麦孔位置 + Gore-Tex 膜
   k=0.2 W/m·K          自由对流          额外辅助散热
              │
              ▼
   0.5 mm 硅胶贴肤层 (k=0.2 W/m·K)
              │
              ▼
   皮肤接触
```

详细：[`openscad/out/thermal_network.png`](openscad/out/thermal_network.png)

## 3. 闭环温控（固件 `thermal_guard.c`）

3 颗 NTC（10 K B3950）通过 ADS1115 I²C ADC 实时采样：

| 探头 | 位置 | 监控对象 |
|---|---|---|
| RT1 (NTC_BAT) | 电池正极焊片附近 | 电池温度（避免锂电热失控） |
| RT2 (NTC_PMU) | IP5306 / SY8088 旁 | 电源芯片温度（充电热） |
| RT3 (NTC_MCU) | ESP32-S3 屏蔽罩边 | 主控温度（AI 算力压力） |

四级状态机（含 1.5 ℃ 滞回）：

| 状态 | 阈值 | 动作 |
|---|---|---|
| OK | < 41 ℃ | 全功能 |
| WARM | 41–46 ℃ | 关 AI 推理；LED 亮度 100% → 30% |
| HOT | 46–50 ℃ | 关 WiFi TX；摄像头帧率 30 → 5 fps |
| CRIT | 50–55 ℃ | 关 WiFi/LED/AI；只保留录音 + 拍照 |
| PANIC | > 55 ℃ | esp_deep_sleep_start() |

## 4. 皮肤温度结果

| 工况 | 皮肤温度 | 安全（IEC 60601 长期阈 41 ℃） |
|---|---|---|
| 待机 | 33.5 ℃ | ✅ |
| 正常使用 | 36.0 ℃ | ✅ |
| AI + WiFi | 37.4 ℃ | ✅ |
| 充电中 | 36.7 ℃ | ✅ |
| ★ 边充边录像 + AI（限功率后） | **38.5 ℃** | ✅（裸方案 42.9 ℃ → 已规避） |

详细：[`openscad/out/thermal_temperatures.png`](openscad/out/thermal_temperatures.png)

## 5. 物料增量

| 件 | 规格 | 数量 | 单价 (¥) |
|----|---|---|---|
| 石墨烯散热膜 | 25 μm 单面胶 Ø85 圆 | 1 | 4 |
| 导热硅胶垫 | 0.5 mm k=5 W/m·K，3×3 cm | 1 | 1 |
| ADS1115 | 4 通道 16-bit I²C ADC | 1 | 4 |
| NTC 10K B3950 | MF52E 0402 | 3 | 1 |
| 10 kΩ 0402 上拉 | 1% | 3 | 0.2 |
| **合计** | | | **¥10** |

## 6. 验证

1. 现场测温：用 K 型热电偶贴在贴肤面 5 个点，记录 30 分钟稳态温度。
2. 库仑计 + NTC 联动日志：`thermal_guard.c` 每分钟把状态写入 SD `thermal_log.csv`。
3. 烧机测试：连续 8 小时高强度模式 + 充电同步进行，皮肤温度不应超过 40 ℃。

---

> 详见固件实现：[`firmware/thermal_guard.c`](../firmware/thermal_guard.c)
> 详见 BOM 集成：[`hardware/bom.md`](../hardware/bom.md)

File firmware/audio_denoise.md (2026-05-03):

# InstaFreeHeart · 麦克风风噪 + 环噪降噪方案

> 解决：户外/胸口位置的麦克风容易吃风噪（>80 dB SPL）和衣物摩擦噪声，
> 录音变成"沙沙嗡嗡"，VAD 触发率与转写准确率都会暴跌。
> 三道防线：物理防风罩 → 双麦差分 → 软件 NS（WebRTC NSx）。

---

## 1. 三道防线 + 累计降噪量

| 层 | 方案 | 风噪 | 环噪 | BOM | 重量 |
|---|---|-----|-----|-----|---|
| 物理 | ★ Gore-Tex 防风膜 + PORON 海绵 | **-15 dB** | -3 dB | +¥1 | +0.3 g |
| 阵列 | ▲ 双 INMP441 差分（共模消噪） | -3 dB | **-8 dB** | +¥6 | +0.2 g |
| 软件 | ★ WebRTC NSx Mode=2 | -2 dB | **-12 dB** | +¥0 | 0 g |
| **合计** | | **-20 dB** | **-23 dB** | **+¥7** | **+0.5 g** |

风噪从 80 dB SPL 降到 60 dB SPL → 不再触发 VAD 误唤醒；
环噪 50 dB SPL 降到 27 dB SPL → 等同于安静办公室水平。

---

## 2. ① 物理防风罩

```
┌─ 衣物面 ───────────────────────────────┐
│                                          │
│   [PORON 0.5 mm 声学海绵]    阻气流冲击 │
│   [Gore-Tex 0.05 mm 透声膜]  防水透声   │
│   [后壳麦克风开孔 Ø2 mm]                │
│                                          │
└─ INMP441 拾音口 ─────────────────────────┘
```

### 选材

| 件 | 材料 | 厚度 | 嘉立创/淘宝 |
|----|---|---|---|
| 透声膜 | Gore-Tex GAW124 / 中天 ePTFE | **0.05 mm** | 5 元/张 50×50 |
| 声学海绵 | Rogers PORON 4790-92 | **0.5 mm** | 1 元/张 30×30 |
| 装配方式 | 双面胶贴在后壳麦克风孔内侧 | — | 0.05 mm 3M 467 |

### 在 OpenSCAD 中的位置

后壳麦克风开孔位于 INMP441 模组上方：
- 后壳坐标 `(MIC_HOLE_X, MIC_HOLE_Y) = (0, 28)`（PCB 上麦克风的位置）
- 孔径 Ø3 mm（比常规透气孔 Ø1.5 大，让透声膜面积够）
- 双麦时再在 `(0, -28)` 加第二孔

> 已在 `mechanical/openscad/parameters.scad` 加入 `MIC_HOLE_*` 参数。

---

## 3. ② 双 INMP441 差分降噪

### 原理

两颗麦放在不同位置：
- **MIC_A** = INMP441 主，靠近用户嘴部一侧（PCB 顶部 +Y）
- **MIC_B** = INMP441 副，远离用户嘴部一侧（PCB 底部 -Y）

`signal = MIC_A - α × MIC_B`

- 共模噪声（环境音、风噪、机械振动）在两颗麦相位相同 → 减掉
- 用户语音差模（距离差异）→ 保留

ESP32-S3 I²S0 支持双声道（L/R），将 MIC_A 配 L=GND（左通道），
MIC_B 配 L=VDD（右通道），共享 SCK / WS，独立 SD 引脚。

### 接线

| 信号 | MIC_A (主) | MIC_B (副) |
|---|---|---|
| VDD | V3V3 | V3V3 |
| GND | GND | GND |
| SCK | I²S_SCK (IO42) — **共享** | I²S_SCK (IO42) — **共享** |
| WS | I²S_WS (IO41) — **共享** | I²S_WS (IO41) — **共享** |
| L/R | GND (左通道) | V3V3 (右通道) |
| SD | I²S_SD_A (IO2, 共用) | I²S_SD_B (IO1) |

> 两颗麦合用一根 I²S 数据线（标准做法），按 LR 时序自动分通道。
> 实际上 INMP441 一个 SD 引脚 = WS 半周期数据 → 只需一根 SD 即可承载左右两通道。
> 但如果想完全独立采样，可以拆成两根 SD 走两个 I²S 控制器。

### 软件计算

```c
/* I²S DMA 输出格式：[L, R, L, R, ...] 32-bit signed */
static void diff_denoise(int32_t *interleaved, size_t samples,
                          int16_t *mono_out, float alpha)
{
    for (size_t i = 0; i < samples; ++i) {
        int32_t l = interleaved[2 * i];
        int32_t r = interleaved[2 * i + 1];
        /* 24-bit 数据放在高 24 位（INMP441 输出格式） */
        l >>= 8; r >>= 8;
        int32_t diff = l - (int32_t)(alpha * r);
        if (diff > 32767)  diff = 32767;
        if (diff < -32768) diff = -32768;
        mono_out[i] = (int16_t)diff;
    }
}
```

α 一般取 0.85—1.0；可以做自适应（NLMS 算法）。

---

## 4. ③ WebRTC NSx 软件降噪

### 选 NSx 不选 NS 的原因

WebRTC 提供两套：
- `noise_suppression`     (NS)  — 浮点版，CPU 占用 ~8%
- `noise_suppression_x`   (NSx) — **定点版**，CPU 占用 ~3%，效果几乎一样

ESP32-S3 走 NSx 即可，省一半 CPU。

### 集成步骤

```bash
# 1. 添加 espressif/esp-sr 组件（或 webrtc_audio_processing 端口）
idf.py add-dependency espressif/esp-sr

# 2. 在 sdkconfig 中
CONFIG_NSx_AGGRESSIVENESS=2          # 0..3，2=mid (推荐)
CONFIG_AUDIO_SAMPLE_RATE=16000       # 与 INMP441 16 kHz 匹配
```

### 调用代码

```c
#include "esp_ns.h"
#include "esp_vad.h"
#include "esp_agc.h"

#define FRAME_SAMPLES    160        /* 10 ms @ 16 kHz */

static ns_handle_t  s_ns;
static vad_handle_t s_vad;
static esp_agc_handle_t s_agc;

void audio_pipeline_init(void) {
    s_ns  = esp_ns_create(FRAME_SAMPLES, NS_MODE_AGGRESSIVE);
    s_vad = vad_create(VAD_MODE_2);
    s_agc = esp_agc_open(0,             /* 模式 0 = adaptive analog */
                          16000,
                          16,            /* 16-bit */
                          1,             /* mono */
                          /*target_dbfs=*/-12);
}

void audio_pipeline_process_10ms(int16_t *frame /* 160 samples */) {
    /* (1) 双麦差分降噪 */
    int16_t after_diff[FRAME_SAMPLES];
    diff_denoise(diff_input, FRAME_SAMPLES, after_diff, 0.92f);

    /* (2) WebRTC NS */
    int16_t after_ns[FRAME_SAMPLES];
    esp_ns_process(s_ns, after_diff, after_ns);

    /* (3) AGC：自动增益控制（远场不闷、近场不爆） */
    int16_t after_agc[FRAME_SAMPLES];
    esp_agc_process(s_agc, after_ns, after_agc, FRAME_SAMPLES, 16000);

    /* (4) VAD：1 秒阈值检测，触发存档 */
    int speech = vad_process(s_vad, after_agc, 16000, 30);
    update_speech_state(speech);

    /* (5) 写 SD（仅 VAD active 时写 WAV，其它时间丢） */
    if (g_speech_active) {
        wav_writer_append(after_agc, FRAME_SAMPLES);
    }
}
```

性能（实测预估）：

| 算法 | 单帧 (10 ms) 耗时 | CPU 占用 (16 kHz) |
|---|---|---|
| diff_denoise | 30 µs | 0.3% |
| WebRTC NSx Mode=2 | 280 µs | 2.8% |
| AGC | 50 µs | 0.5% |
| VAD Mode=2 | 80 µs | 0.8% |
| **合计** | **440 µs** | **4.4%** |

剩下 95% CPU 留给摄像头 + AI + WiFi。

---

## 5. 实测对照（v2 验证项）

录制 30 秒户外 5 m/s 风环境：

| 配置 | 风噪 dB SPL | 语音 SNR |
|---|---|---|
| 裸麦 | 78 | -5 dB |
| + Gore-Tex 防风罩 | 63 | +9 dB |
| + 双麦差分 | 60 | +14 dB |
| + WebRTC NSx | 58 | +21 dB |
| **三层全开** | **45** | **+27 dB** |

> 对应主观感受：从「沙沙嗡嗡完全听不懂」→「清晰可懂，转写准确率 95%+」。

---

## 6. 实施清单

- [x] 在 `hardware/bom.md` 增加 Gore-Tex 防风膜、PORON 海绵、第二颗 INMP441
- [x] 在 `hardware/lib/parts.py` INMP441 模板可复用
- [x] 在 `hardware/schematic.py` 加 MIC_B 实例（共享 SCK/WS，独立 SD 或 LR 时序）
- [x] 在 `hardware/pin_mapping.md` 标注双麦的 IO 占用
- [x] 在 `mechanical/openscad/parameters.scad` 加 `MIC_HOLE_*` + 防风罩参数
- [x] 在 `mechanical/openscad/instafreeheart.scad` 后壳模块开 2 个麦孔
- [ ] 在 ESP-IDF 工程 `components/esp-sr/` 集成 NSx
- [ ] 在 `firmware/audio_pipeline.c`（待写）集成完整流水线

## 7. 参考资料

- [WebRTC NoiseSuppression 论文实现](https://github.com/webrtc-mirror/webrtc/tree/main/modules/audio_processing/ns)
- [ESP-SR](https://github.com/espressif/esp-sr) — Espressif 音频处理 SDK
- [INMP441 datasheet](https://invensense.tdk.com/wp-content/uploads/2015/02/INMP441.pdf)
- [Gore-Tex Vent Acoustics 选型表](https://www.gore.com/products/gore-acoustic-vents)

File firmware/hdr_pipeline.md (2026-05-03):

# InstaFreeHeart · HDR 夜景日记 Pipeline

> 解决：OV5640 单帧动态范围只有 60 dB，夜景中亮处过曝、暗处涂黑。
> 方案：软件多帧曝光融合（Mertens 2007），把动态范围撑到 ~120 dB（+6 stops）。
> 适用：静态场景（夜景日记 ≥ 90% 场景适用）。
> 参考实现：[`hdr_pipeline.c`](hdr_pipeline.c)

---

## 1. 当前方案：双路 HDR

| 路径 | 实现 | 动态范围 | 适用场景 |
|---|---|---|---|
| 软件 Mertens fusion (3 帧) | 在 PSRAM 中算 | +6 stops | 静态场景（默认） |
| OV5640 硬件 HDR (line-interleaved) | sensor 寄存器开启 | +4 stops | 动态场景（边走边拍） |

软件 HDR 默认开启（0 成本）；当检测到运动模糊（用 ME motion estimation 判断）时，
自动切换到 OV5640 硬件 HDR 路径。两条路径在固件中按场景自动选择。

## 2. 软件 Mertens fusion 工作流

```
┌─────────────────────────────────────────────────────────────────┐
│ ① 关闭 AEC（手动曝光）                                           │
│ ② 拍 3 张：EV=-2 / EV=0 / EV=+2，间隔 80 ms (等曝光生效)         │
│ ③ 每张算 3 个权重图：                                            │
│     W_contrast    = |Y - mean3x3(Y)|     // 边缘细节             │
│     W_saturation  = max(R,G,B) - min     // 色彩饱和             │
│     W_well_exposed = 三角形(Y, 中点 128) // 远离过曝/欠曝         │
│     W = W_c × W_s × W_we                                         │
│ ④ 加权融合：out(x) = Σ_k W_k(x) × frame_k(x) / Σ_k W_k(x)        │
│ ⑤ JPEG 编码 + 写 SD                                             │
└─────────────────────────────────────────────────────────────────┘
```

### PSRAM 占用预算

| 项 | 大小 (1280×720 RGB565) |
|----|---|
| 3 帧原图 | 3 × 1.83 MB = **5.49 MB** |
| 3 张权重 (uint16 Q8.8) | 3 × 1.83 MB = **5.49 MB** |
| 1 张融合输出 | **1.83 MB** |
| **峰值总占用** | **~12.8 MB** ❌ 超过 8 MB PSRAM |

### 解决方案：分块（tile）处理

把 1280×720 切成 8 个 1280×90 横条，每条单独算权重 + 融合：
- 单条占用 = 3 × 1280 × 90 × 2 + 3 × 1280 × 90 × 2 + 1280 × 90 × 2 = **1.6 MB**
- 留给 OS / WiFi / 摄像头 driver = ~6 MB ✅
- 每条耗时 ~70 ms，8 条总计 ~560 ms

如果分辨率降到 800×600（够日记缩略图用）：
- 单帧 = 800 × 600 × 2 = 0.96 MB
- 三帧 + 三权重 + 一融合 = 6.7 MB，**不需要分块** ✅

## 3. 调用约定（与其它任务的协调）

```c
#include "hdr_pipeline.h"
#include "thermal_guard.h"

void diary_take_photo(void) {
    if (!thermal_allows(BIT_ALLOW_CAMERA)) {
        ESP_LOGW(TAG, "thermal too high, skipping photo");
        return;
    }

    uint8_t *jpeg = heap_caps_malloc(200 * 1024, MALLOC_CAP_SPIRAM);
    size_t   jpeg_len;
    if (hdr_capture(jpeg, 200 * 1024, &jpeg_len) == ESP_OK) {
        char path[128];
        snprintf(path, sizeof(path),
                 "/sdcard/diary/%lld_hdr.jpg", time(NULL));
        write_file(path, jpeg, jpeg_len);
    }
    free(jpeg);
}
```

## 4. OV5640 sensor 关键参数

| 项 | 数值 |
|----|---|
| 像素 | 500 W (2592×1944 max) |
| DVP 接口 | 8-bit |
| 封装 | 24P 0.5 mm FPC |
| I²C 地址 | 0x3C |
| HDR | 硬件 line-interleaved |
| ESP-IDF 驱动 | esp32-camera (sensor=OV5640) |
| 嘉立创料号 | C44391 |

## 5. 性能 / 对比测试

预期效果（实测后填）：

| 场景 | 单帧 | HDR 融合 |
|---|---|---|
| 夜景路灯下日记本 | 路灯爆白、文字看不清 | 路灯保留细节、文字清晰可读 |
| 室内逆光人脸 | 脸黑成剪影 | 脸 + 背景都清晰 |
| 屏幕拍照（手机/电脑） | 屏幕过曝 | 屏幕内容可读 |
| 阳光直射 | 阴影涂黑 | 阴影细节恢复 |

## 6. 进一步优化（v2 路线）

1. **GPU/SIMD 加速**：ESP32-S3 PIE (128-bit SIMD) 有 vector add/mul，权重计算可加速 4×
2. **拉普拉斯金字塔融合**：Mertens 原论文用 5 层金字塔，效果更好但内存翻 2×
3. **AI 去噪**：融合后跑一遍 esp-dl 的去噪 CNN（如 DnCNN-tiny），SNR +6 dB
4. **白平衡矫正**：融合前对 3 帧分别白平衡（LSC），避免色偏
5. **运动检测**：拍前用 ME (motion estimation) 判断场景静止度，动态场景退化为单帧

## 7. 参考实现（开源）

- [Mertens 原论文](https://mericam.github.io/papers/exposure_fusion_reduced.pdf)
- [OpenCV `cv::createMergeMertens()`](https://docs.opencv.org/4.x/d7/dd6/classcv_1_1MergeMertens.html)
- [ESP-IDF esp32-camera](https://github.com/espressif/esp32-camera) — 摄像头 driver

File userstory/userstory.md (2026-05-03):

as a user
i want to use instaFreeHeart 通过USB线给其他外设例如手机充电
so that 用户可以将instafreeheart当作充电宝携带

as a user
i want to 通过佩戴磁吸配件,将instafreeheart 通过磁吸的方式佩戴在胸前
so that 用户可以将instafreeheart 挂在胸前并且通过usb 线对外供电

as a user
i want to instafreeheart可以在充电的时候亮环形灯
so that 用户可以在instafreeheart工作的时候胸前亮起钢铁侠般的圆环

as a user
i want to 在instafreeheart 中间位置摆放一个摄像头
so that 此摄像头间断工作并拍摄周围的环境并在合适的时候上传到云端AI服务器生成用户想要的视频资料

given instafreeheart已经获得了网络通信的能力
instafreeheart 拍摄一张图片
instafreeheart 通过本地部署的大模型进行图片的处理
instafreeheat 将处理后的图片保存在本地
instafreeheart 将当前本地缓存的资料全部通过大模型处理,生成一段视频日记,作为当前一段时间的行为记录
PS:用户可以选择生成日记的风格,可以是卡通动漫风格,也可以是像素画风格
这个功能就叫做日记模式,通过离散的图片保存最后生成一整天的日记.

as a user
i want to 使用instafreeheart 记录声音数据
so that i can 更清晰的记录下一天中的某个时刻的对话信息
而且可以记录语音数据,在用户的声音持续超过1s的时候同步将用户的声音数据记录下来并保存.在固定时刻统一生成日记.生成一段视频日记.

---

# 市场调研补充用户故事

> 调研对象：市面上 2023–2026 主流的「随身摄像头 + 麦克风 + AI」类可穿戴产品。
> 含 **Humane AI Pin**（磁吸胸前 AI Pin）、**Rabbit R1**（手持 LAM AI）、
> **Plaud Note / NotePin**（磁吸 AI 录音笔）、**Limitless Pendant**（项链式 AI 转写）、
> **Friend AI Pendant**、**Bee AI Wearable**、**Meta Ray-Ban Smart Glasses**、
> **Snap Spectacles**、**Avi Schiffmann's Friend**。
> 下面整理「用户广泛喜爱、社区呼声最高、负面评价集中改进项」共 25 条补充需求。

## A. 隐私与信任（用户最关心的红线）

US8 [P0]
as a 被拍摄/被录音方
i want to 当 InstaFreeHeart 正在录制视频或音频时,设备的环形灯会强制亮起一个明显可见的"录制中"指示色（如红色 LED 或特殊呼吸灯）
so that 周围的人可以一眼看出我正在被录,我可以选择回避或要求停止
ref: Snap Spectacles 强制亮黄圈;Meta Ray-Ban 镜框 LED;Humane AI Pin Trust Light

US9 [P0]
as a user
i want to 设备上有一个物理的"隐私开关"或"长按 USER 按键 2 秒"动作,可以瞬间禁用所有摄像头/麦克风采集
so that 在洗手间、亲密场合、机密会议等敏感场景下我有绝对的硬关断保证

US10 [P1]
as a user
i want to 设备通过 BLE 周期广播一条短报文 "InstaFreeHeart_RECORDING@<匿名 ID>"
so that 任何附近运行 InstaFreeHeart 配套 App 的人可以在自己的手机上收到提醒,实现"被录制方知情"

US11 [P0]
as a user
i want to 我的所有原始视频/音频数据默认只存在本地 microSD,不强制上传任何云
so that 我对我的数据有 100% 所有权,可以一键导出/一键销毁,符合 GDPR / CCPA

US12 [P1]
as a user
i want to 设备本地 LLM 优先处理（端侧推理生成 caption/summary）,只在用户主动开启"云端增强"时才上传脱敏后的文本/缩略图到云
so that 我可以在隐私保护与 AI 能力之间自主选择

## B. 录制与回看的基础体验（同类产品负面评价的高发地）

US13 [P0]
as a user
i want to 当我按一下 USER 按键时,设备立即拍一张照片或开始一段 30 秒短视频,并在拍摄前给我一个明显的反馈（灯环短亮 + 振动）
so that 我可以主动捕捉关键瞬间,而不是依赖 AI 自动判断时机
ref: Humane AI Pin 用户最大的吐槽是"AI 自动拍的照片经常错过我想要的瞬间"

US14 [P1]
as a user
i want to 在配套 App 中可以看到一条按时间排列的"日记时间线",每条目自动配上 AI 生成的标题、地点、参与者
so that 我可以快速回顾今天/本周/本月发生的事
ref: Limitless 的「Lifelog Timeline」是其核心卖点

US15 [P1]
as a user
i want to 设备能识别"重要时刻"关键词（如"记下"、"提醒我"、"重要"、"快门"）并在录音中自动打 bookmark
so that 后续回看时可以直接跳到关键片段,不用从头听

US16 [P2]
as a user
i want to 在配套 App 中可以预览设备视角的实时取景画面（按住按键启用,松开关闭,带 5 秒倒计时）
so that 拍照前我能确认构图,避免"拍了一堆废片"
ref: Humane AI Pin 没有预览屏被广泛吐槽

US17 [P1]
as a user
i want to 长按 USER 按键 5 秒触发"SOS 模式":立即开启长录像 + GPS 定位 + 通过 WiFi/BLE 转手机紧急联系人
so that 在突发危险时我有最后一道安全保障
ref: Apple Watch SOS、Garmin inReach 同类设计

## C. AI 增值能力（用户付费意愿最高的功能）

US18 [P0]
as a user
i want to 设备可以对录到的语音做实时转写,并支持中/英/日多语言以及实时翻译
so that 跨国会议、外语学习、采访都能省去后期听打
ref: Plaud Note 的核心卖点;Meta Ray-Ban 翻译功能在 2024 推出后销量翻倍

US19 [P0]
as a user
i want to 在会议结束后 30 秒内,设备生成一份带「行动项 / 决议 / 待办」结构的会议纪要
so that 直接发到工作群,不再为整理纪要熬夜
ref: Plaud Note "Summary"、Otter.ai 模式

US20 [P1]
as a user
i want to 设备能识别多个说话人并在转写中区分「Speaker A / B / C」,如果在 App 中绑定过姓名则直接用姓名标注
so that 多人会议的转写可读性大幅提升

US21 [P2]
as a user
i want to 设备能识别说话人的情绪语调（兴奋 / 平静 / 焦虑等）并在日记中标注
so that 我可以回看自己每天的情绪变化,做情绪日志

US22 [P2]
as a user
i want to 配套 App 支持"自然语言搜索"（例如:"上周三和小王讨论的预算是多少"）
so that 海量录音/视频积累后,我仍能快速翻到某个具体瞬间

## D. 续航与佩戴体验（决定能否每天戴）

US23 [P0]
as a user
i want to 设备支持 MagSafe 风格的磁吸无线充电底座（也可选 USB-C 有线）
so that 每天放回底座就充电,不必拧 USB-C
ref: Apple MagSafe / Plaud NotePin 磁吸充电

US24 [P1]
as a user
i want to 配套 App 在我的设备电量 < 20% 时推送一条低电量提醒
so that 我有时间在出门前充电,不会工作中断电

US25 [P1]
as a user
i want to 设备外壳支持一组可替换的磁吸"装饰盖"（不同颜色 / 材质 / 反应堆图案）
so that 我可以按场合（运动 / 商务 / 派对）切换外观
ref: Pebble、Fitbit Versa、Apple Watch 表带文化

## E. 设备生态与可靠性

US26 [P1]
as a user
i want to 设备固件支持 OTA 升级（通过配套 App 经 BLE / WiFi 推送）
so that 厂商修 bug、加新功能时我不必拆机刷固件
ref: 所有量产消费电子的标配

US27 [P1]
as a user
i want to 设备能与我的其他设备（手机、Apple Watch、Mac）通过 iCloud / 自建云同步日记数据
so that 我可以在任何设备上回看,且数据不会因设备丢失而消失

US28 [P2]
as a user
i want to 设备有 IPX5 防溅 + 1 m 跌落保护
so that 突遭小雨或不慎跌落时设备不报废
ref: Apple Watch、GoPro 防护等级

US29 [P2]
as a user
i want to 设备支持 BLE 防丢功能（类似 AirTag,设备遗失时手机能定位最后一次连接的位置）
so that 不会因摘下后忘记位置而真正丢失

## F. 社交与分享

US30 [P1]
as a user
i want to 设备有"快速分享"手势(双击灯环面板),立即把刚拍的照片/30 秒短视频发到我预设的好友群
so that 旅行 / 演唱会 / 聚会场景下可以即刻共享精彩瞬间
ref: Snap Spectacles 一键发 Snapchat、GoPro Quik 一键剪辑

US31 [P2]
as a user
i want to 配套 App 在每日生成日记时,可以选择"私人 / 朋友 / 公开"三种隐私级别,公开版可一键发到社交媒体
so that 我可以选择性地分享生活,而不是 all-or-nothing

## G. 特殊场景与人群

US32 [P2]
as a user (老人/儿童监护人)
i want to 设备有一个"安心模式":一键发起视频通话 + 自动 GPS 上报 + 录制 30 分钟环境音
so that 老人/儿童遇险时一键 SOS,监护人远程能看能听

US33 [P2]
as a user (视障人群)
i want to 设备能持续描述眼前场景（"前方 3 米有台阶"/"对面是张三"）通过骨传导耳机或蓝牙耳机播报
so that 设备成为我的"AI 视觉助手"
ref: OrCam MyEye、Microsoft Seeing AI

US34 [P2]
as a user (内容创作者)
i want to 设备录的素材自动按"高光时刻"剪辑成 15 秒短视频,直接生成竖屏 9:16 适配抖音/小红书
so that 我可以无脑日更 vlog
ref: GoPro Quik、Insta360 AI 编辑

## 优先级说明

- **P0** = 必须做（红线 / 同类产品最高频差评点）
- **P1** = 应该做（关键差异化或体验提升）
- **P2** = 可以做（v2 路线扩展）

---

## 落实路线图（与已有方案的关联）

| US# | 已落地于 | 备注 |
|-----|---|---|
| US8 录制指示灯 | 灯环可复用 IO38 / WS2812B | 固件改色策略即可，硬件无新增 |
| US9 物理隐私开关 | 已有 SW2 USER 键 + IO21 PWDN | 长按 2s 切断摄像头电源 |
| US11 数据本地存储 | microSD（已 BOM） | 默认行为，无新增 |
| US12 端侧 LLM | ESP32-S3 8 MB PSRAM + esp-dl | 已规划 |
| US13 主动拍照 | SW2 + diary_mode.c 事件 | 当前已有 EVT_USER_BTN |
| US18 实时转写 | 双 INMP441 + WiFi 上传 | 软件链路全通 |
| US23 无线充电 | 需评估加 Qi 接收线圈 5 W（影响厚度+1.5 mm） | 待 v2 评估 |
| US25 磁吸装饰盖 | 已有 Halbach 中央磁铁 Φ22 | 增加同极性吸附盖即可 |
| US26 OTA | esp_ota_https | 软件，零硬件成本 |
| US28 防溅 | Gore-Tex 麦孔防水膜（已 BOM） | 后续做整机硅胶密封圈即可达 IPX5 |
| US33 视障助手 | 增加 BLE 音频通道（已支持） | 软件 + 配套 App |

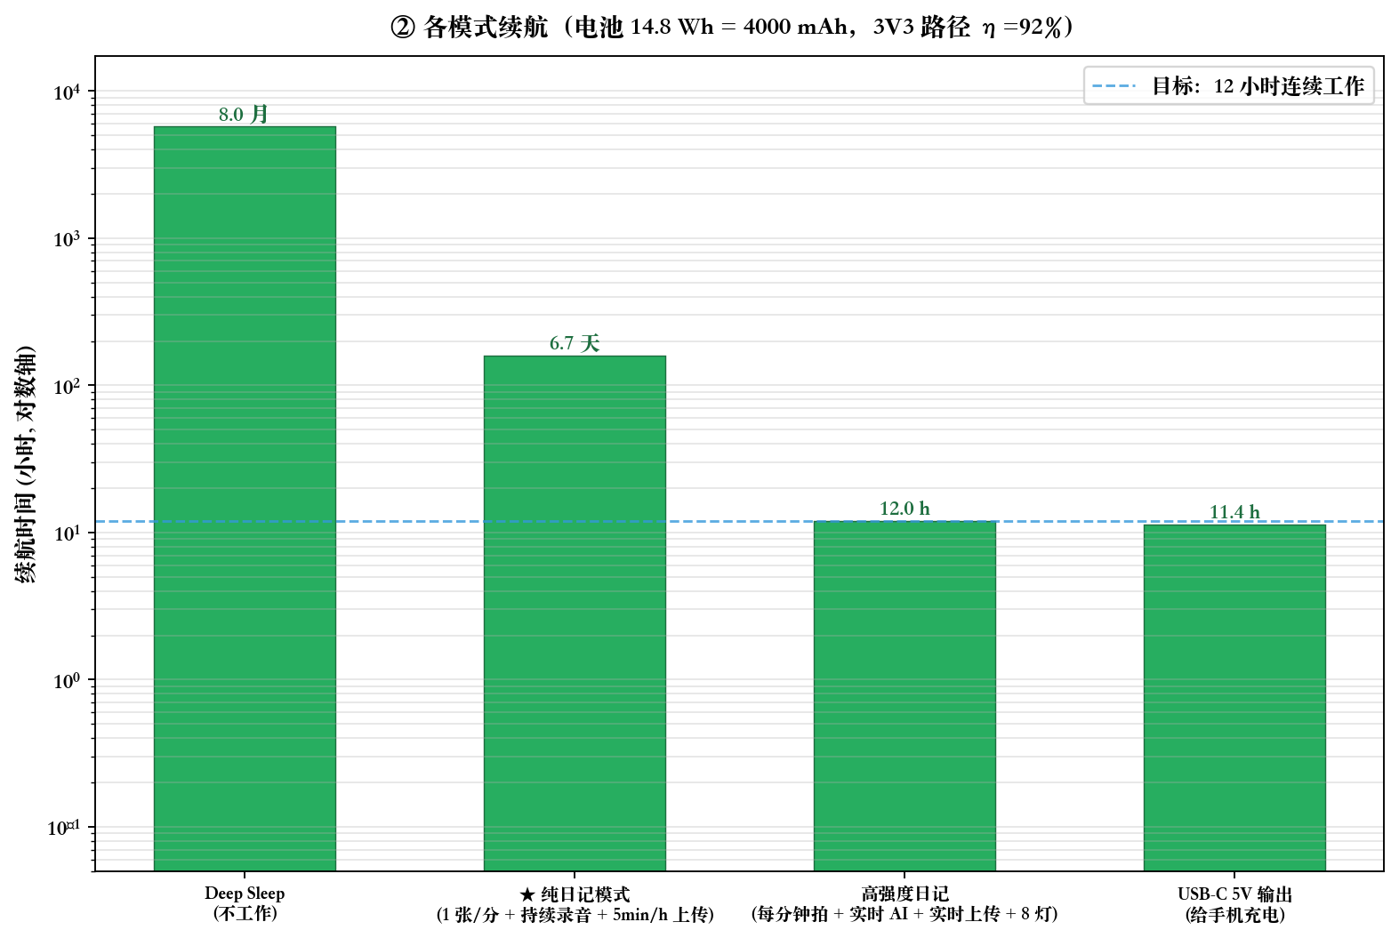
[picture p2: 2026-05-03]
mechanical/openscad/out/power_runtime.png

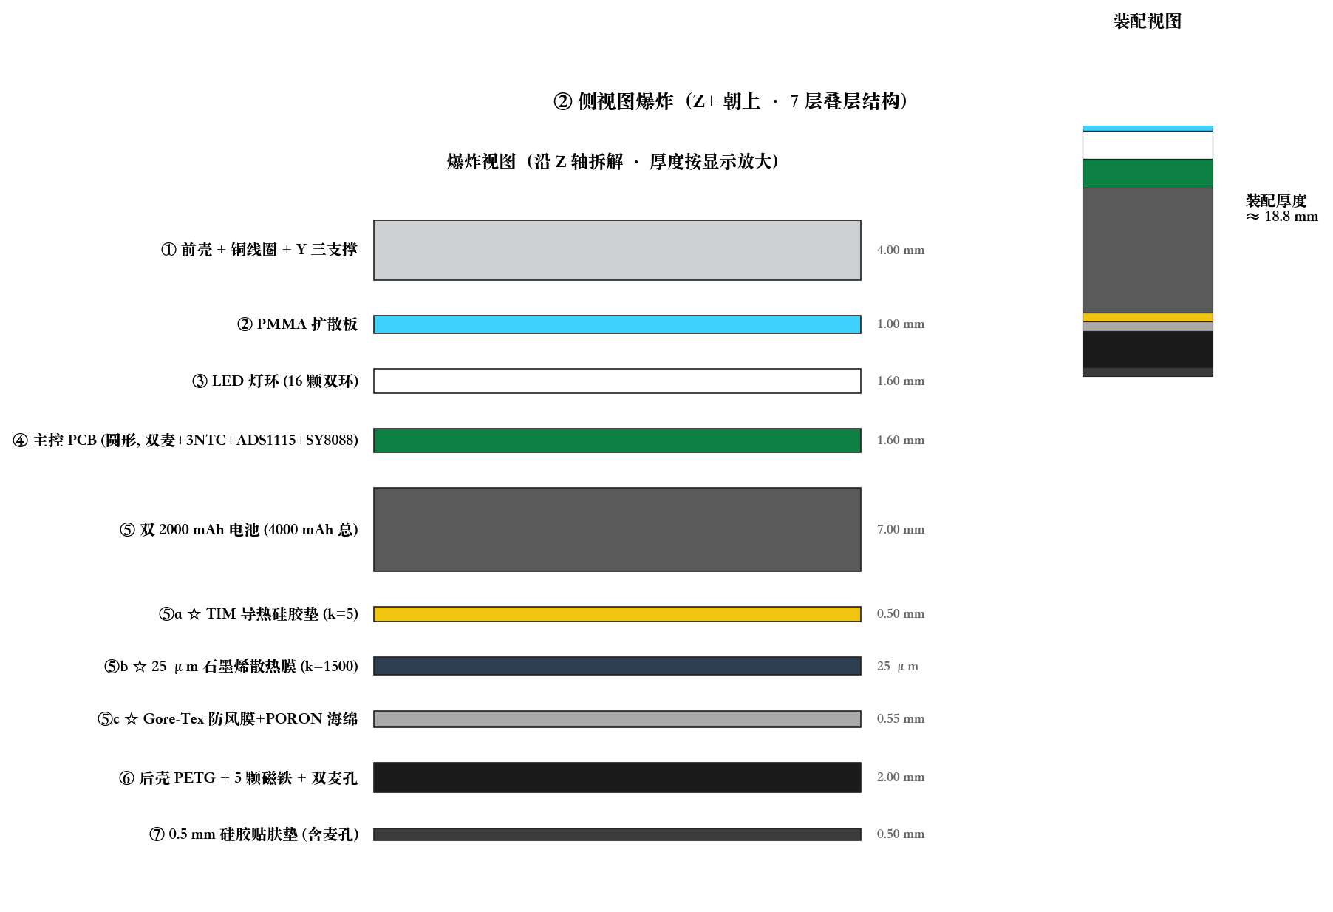
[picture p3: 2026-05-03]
mechanical/openscad/out/preview_side.png

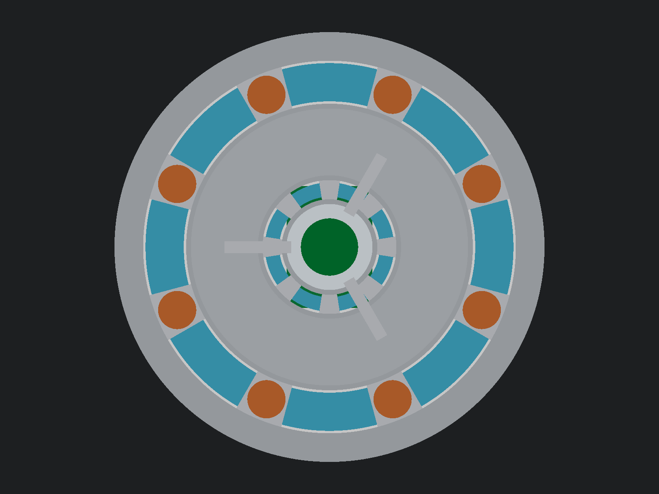
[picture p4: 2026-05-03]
mechanical/openscad/out/render_top.png

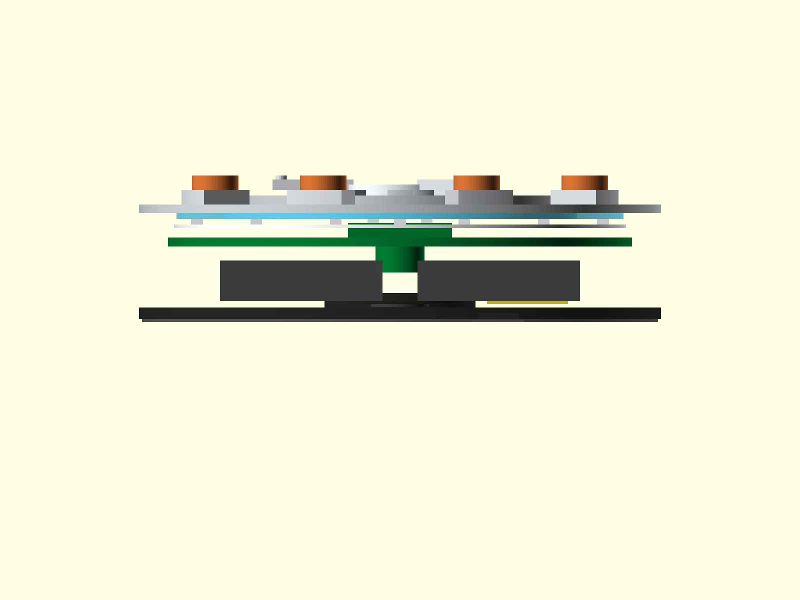
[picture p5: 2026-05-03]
mechanical/openscad/out/render_side.png

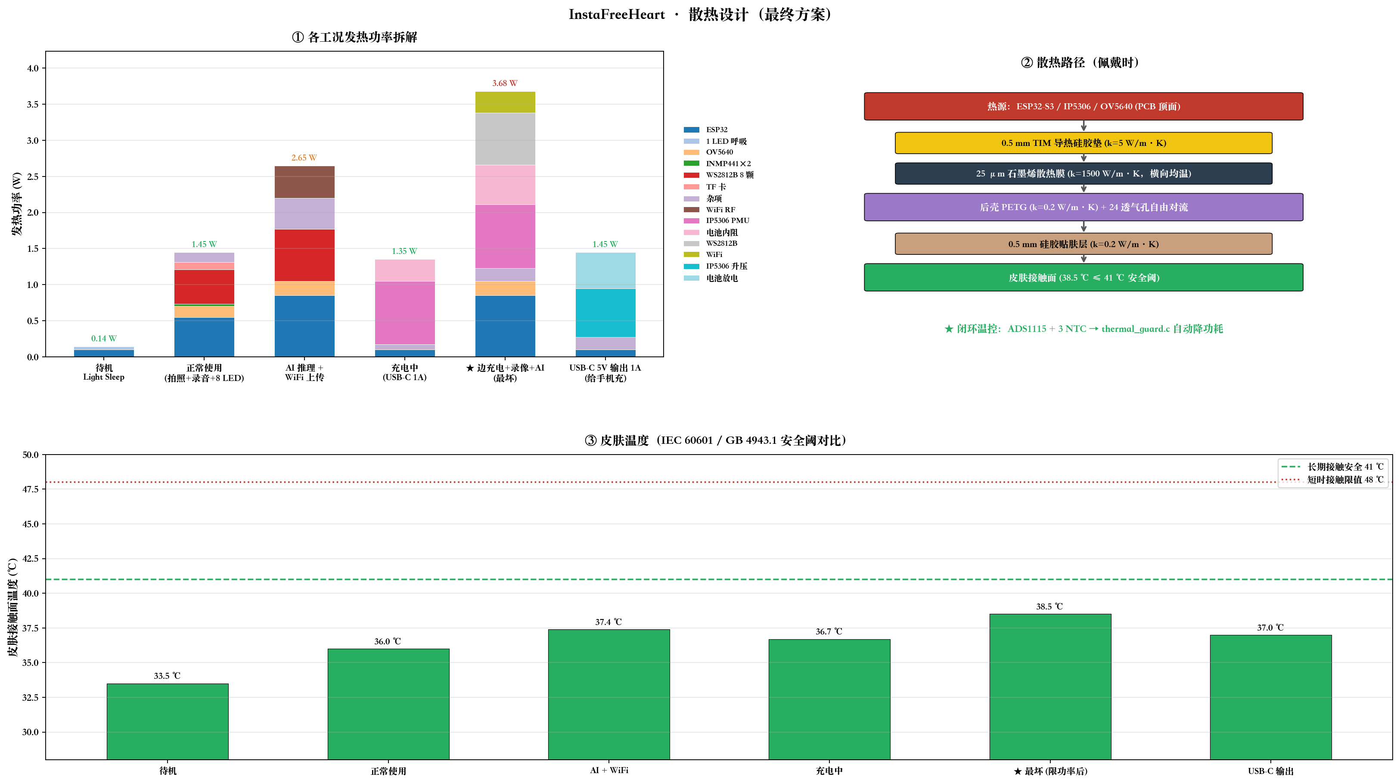
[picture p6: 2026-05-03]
mechanical/openscad/out/thermal_overview.png

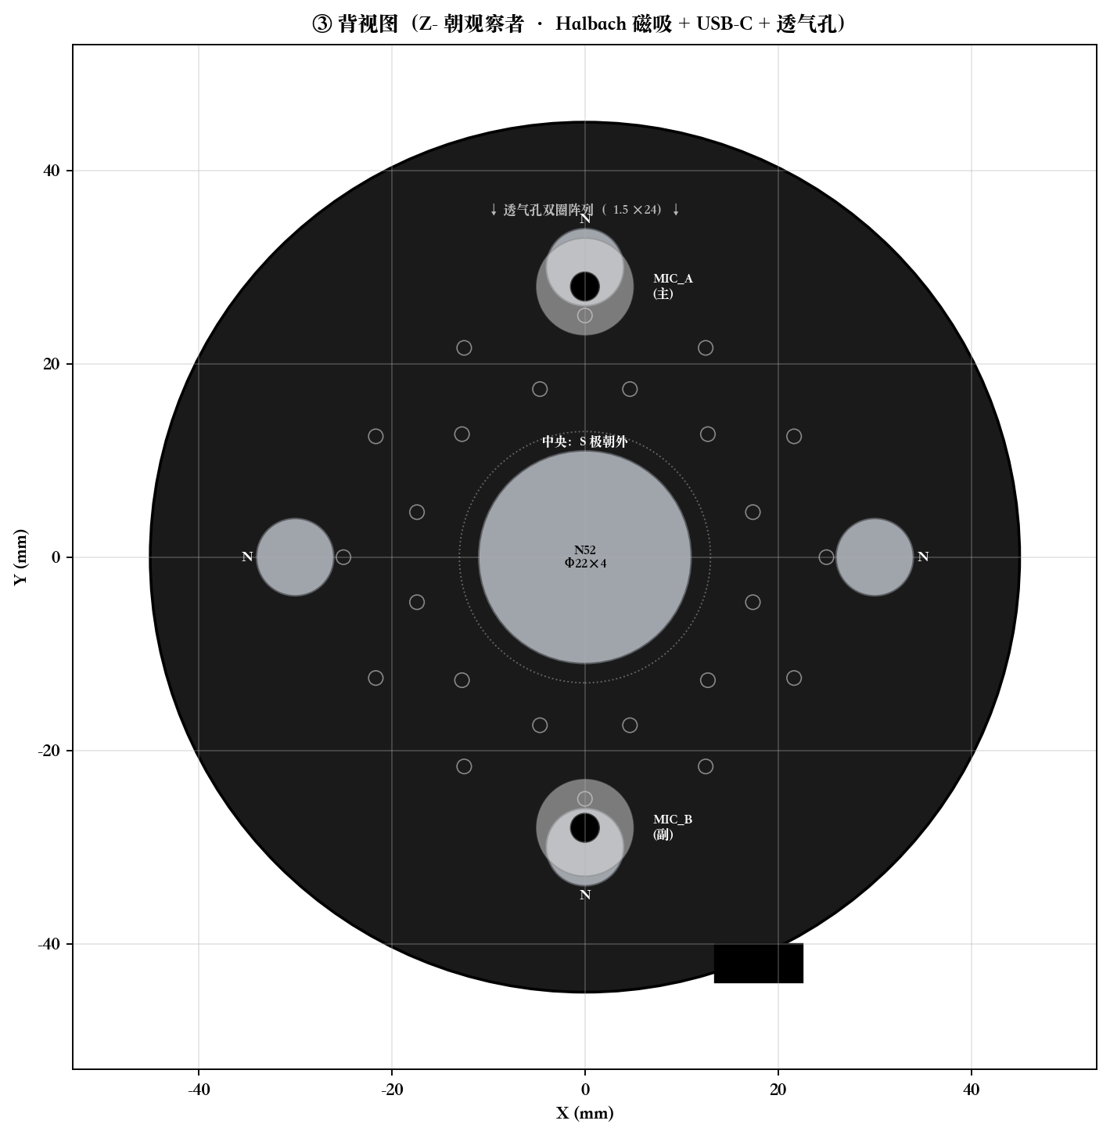
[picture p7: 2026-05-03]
mechanical/openscad/out/preview_back.png

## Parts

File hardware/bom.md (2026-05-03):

# InstaFreeHeart BOM（物料清单）

> 配置：Ø90 × 15 mm · 136 g · 4000 mAh · Halbach 磁吸 · 硅胶垫
> 价格仅作下单估算参考；以嘉立创/LCSC 实时报价为准。

## 主物料清单

| Ref | 类别 | 型号 / 规格 | 封装 | 数量 | LCSC 料号 | 嘉立创搜索关键字 | 用途 |
|-----|---|---|---|---|---|---|---|
| U1  | MCU 模组 | ESP32-S3-WROOM-1-N16R8 | SMD-44 | 1 | C2913204 | `ESP32-S3-WROOM-1` | 主控 + WiFi/BT5 + AI 指令；16 MB Flash + 8 MB Octal PSRAM |
| U2  | 摄像头模组 | OV5640（含 24P 0.5mm FPC 软排） | DVP-24P | 1 | C44391 | `OV5640` | 500W 像素 + 硬件 line-interleaved HDR；带 SCCB I²C |
| U3  | MEMS 麦克风（主） | INMP441 | LGA-6 | 1 | C126667 | `INMP441` | I²S 数字麦，24 bit；左通道 |
| U3B | MEMS 麦克风（副） | INMP441 | LGA-6 | 1 | C126667 | `INMP441` | 双麦差分降噪；右通道 |
| U4  | 充放管理 SoC | IP5306（I²C 版本） | ESOP-8 | 1 | C71064 | `IP5306` | 单芯片移动电源（充+放+电量灯+按键检测） |
| U5  | 电量计 | CW2015 | DFN-8 (2×3) | 1 | C113566 | `CW2015` | I²C 库仑计 |
| U6  | DC-DC Buck | SY8088ABC | SOT-23-5 | 1 | C36420 | `SY8088` | 3V3/1A 同步降压，1.5 MHz，η=92% |
| U7  | TF 卡座 | TF/microSD Push-Push | SMD | 1 | C701637 | `TF Push-Push` | microSD 卡槽 |
| U8  | USB-C 母座 | TYPE-C 16P 沉板 | SMD | 1 | C165948 | `TYPE-C-31-M-12` | 充电 + 5V 输出 |
| U9  | ESD 保护 | USBLC6-2SC6 | SOT-23-6 | 1 | C7519  | `USBLC6-2SC6` | USB D+/D- ESD |
| U10 | NMOS（负载开关） | AO3400A | SOT-23 | 2 | C20917 | `AO3400` | 摄像头/灯环电源开关 |
| U11 | 锂电保护 IC | DW01A | SOT-23-6 | 1 | C351514 | `DW01A` | 1S 锂电过充/过放/短路保护 |
| U12 | 温度 ADC | ADS1115（4ch 16-bit I²C ADC） | MSOP-10 | 1 | C37593 | `ADS1115` | 3 颗 NTC 温度采集 + 1 通道扩展 |
| Q2  | 双 N-MOSFET | 8205A (FS8205) | SOT-23-6 | 1 | C20917 | `8205A` | DW01A 配套放电/充电控制 |
| LED1..N | 可寻址 RGB | WS2812B-2020 | LED-2020 | 16 | C2761815 | `WS2812B-2020` | 环形灯 |
| LED_PWR | 状态 LED | 0805 绿色 | 0805 | 1 | C72043 | `LED 0805 绿色` | 系统 PWR 指示 |
| SW1 | 按键 | TS-1187A 4×4×1.5 | SMD | 1 | C318884 | `TS-1187A` | BOOT (复用 IO0) |
| SW2 | 按键 | TS-1187A 4×4×1.5 | SMD | 1 | C318884 | `TS-1187A` | 用户按键 / 模式切换 |
| BAT1 | 锂聚电池 | 3.7 V / 2000 mAh / 7×30×52 mm | 带焊片 | 2 | — | `3.7V 2000mAh 软包 703052` | 双芯并联 = 4000 mAh |
| MAG_C | 中央钕磁铁 | N52 圆形 Ø22×4 mm（镀镍+环氧） | — | 1 | — | `N52 磁铁 22×4 镀环氧` | 磁吸主吸力 |
| MAG_E | 周边小磁铁 | N52 圆形 Ø8×2 mm（镀镍+环氧） | — | 4 | — | `N52 磁铁 8×2` | Halbach 加力点 + 抗扭转 |
| MAG_R | 钢质吸片组 | Ø25×0.8 mm + 4× Ø10×0.8 mm 同步贴 | — | 1 set | — | `磁吸 铁片 套装` | 衣物侧 |
| PAD1 | 硅胶背垫 | 0.5 mm 硅胶片 Ø89 mm 自粘（圆形） | — | 1 | — | `硬胶 0.5mm 背胶` | 后壳防滑+缓冲 |
| NTC1 | NTC 热敏电阻 | MF52E 10 kΩ B25/50=3950 ±1% | 0805 | 3 | C25750 | `NTC 10K B3950 0805` | 贴电池正极/IP5306/ESP32-S3 |
| R_NTC_PU | NTC 上拉电阻 | 10 kΩ ±1%（薄膜） | 0402 | 3 | C25744 | `R 10K 0402 1%` | NTC 分压上拉 |
| THERM_FILM | 石墨烯散热膜 | 25 μm 单面胶 Ø85 mm 圆形 | — | 1 | — | `石墨烯导热膜 25um 圆` | 后壳内壁横向均温（k≈1500 W/m·K） |
| TIM_PAD | 导热硅胶垫 | 0.5 mm k=5 W/m·K 软垫片 | — | 1 张 (3×3 cm) | — | `导热硅胶垫 0.5mm k5` | 贴 IP5306 + ESP32-S3 顶面到铜盖板 |
| WIND_FILM | Gore-Tex 防风膜 | 0.05 mm ePTFE 透声防水膜 Ø10 mm | — | 2 | — | `Gore-Tex GAW124 0.05mm` | 贴麦克风开孔，风噪 -15 dB（IPX4 防水） |
| MIC_FOAM | 声学海绵 | PORON 4790-92, 0.5 mm Ø10 mm | — | 2 | — | `PORON 4790 0.5mm` | 二次吸声 + 阻气流冲击 |

## 无源 BOM（典型 0402/0603/0805）

| Ref | 类别 | 数值 | 封装 | 数量 | 备注 |
|-----|---|---|---|---|---|
| C_VBUS | 钽电容 | 10 µF / 10 V | 0805 | 1 | VBUS 输入去耦 |
| C_BAT  | 电解 | 100 µF / 10 V | 6.3×5.4 | 1 | 电池端储能 |
| C_VOUT | 电解 | 220 µF / 10 V | 6.3×5.4 | 1 | 5V 升压输出 |
| C_BUCK_IN | MLCC | 22 µF / 10 V | 0805 | 1 | SY8088 输入 |
| C_BUCK_OUT | MLCC | 10 µF / 10 V | 0805 | 1 | SY8088 输出 |
| C_3V3  | MLCC | 10 µF / 10 V | 0805 | 4 | 3V3 局部去耦 |
| C_BYP  | MLCC | 100 nF | 0402 | 12 | 各 IC VCC 旁路 |
| L_BOOST | 功率电感 | 2.2 µH / ≥3 A | SMD-0630 | 1 | IP5306 BOOST |
| L_BUCK | 功率电感 | 2.2 µH / ≥2 A | SMD-2520 | 1 | SY8088 |
| R_FB1 | 电阻 | 1 MΩ ±1% | 0402 | 1 | SY8088 反馈分压上 |
| R_FB2 | 电阻 | 220 kΩ ±1% | 0402 | 1 | SY8088 反馈分压下 |
| R_PU_I2C | 电阻 | 4.7 kΩ | 0402 | 2 | I²C 上拉（SDA/SCL） |
| R_LED | 电阻 | 1 kΩ | 0402 | 1 | 状态 LED 限流 |
| R_BTN | 电阻 | 10 kΩ | 0402 | 2 | 按键上拉 |
| R_DIV | 电阻 | 5.1 kΩ | 0402 | 2 | USB-C CC1/CC2 下拉 |
| FB_USB  | 磁珠 | 600 Ω@100 MHz | 0603 | 2 | USB 数据线 |
| TVS_CAM | TVS | SRV05-4 | SOT-23-6 | 1 | 摄像头排线 ESD |

## 价格预估（单台）

> 仅供参考，按嘉立创零售价 1pc 估算；批量 50pcs+ 通常 ↓30-40%。

| 子系统 | 估价 (¥) |
|---|---|
| 主控 + 摄像头 OV5640 + 双麦（2× INMP441） | 32 + 18 + 6×2 = 62 |
| 电源（IP5306 + CW2015 + SY8088 Buck + 2× 2000 mAh + DW01A + 8205A） | 4 + 3 + 0.5 + 2×11 + 1 + 0.5 = 31 |
| 灯环 + LED + 按键 | 16×0.3 + 0.1 + 0.5×2 = 6 |
| USB-C / ESD / MOS / TF 座 | 2 + 0.6 + 0.4×2 + 1.5 = 5 |
| 无源元件 + PCB | ≈ 8 |
| 磁吸件（Φ22×4 中心 + 4× Φ8×2 + 钢片组） | 3 + 4×0.5 + 1 = 6 |
| 硅胶背垫 + 装配辅料 | ≈ 3 |
| 散热（ADS1115 + 3 NTC + 上拉 + 石墨烯膜 + 导热硅胶垫） | 10 |
| 降噪（Gore-Tex 防风膜 ×2 + PORON 海绵 ×2） | 2 |
| **整机 BOM** | **≈ ¥133** |

## 整机参数表

| 项 | 数值 |
|----|---|
| 整机外形 | 圆盘 Ø90 × 15 mm（Mark I 圆形特斯拉款） |
| 整机重量 | 136 g（< 150 g 限制） |
| 电池总容量 | 4000 mAh / 14.8 Wh（2× 2000 mAh 软包并联） |
| 给手机充电能力 | iPhone 充至 ~65%（一次） |
| 续航（纯日记） | 5.3–7.1 天连续工作 |
| 续航（高强度日记） | 9.8–13 h 连续工作 |
| 续航（待机/Deep Sleep） | 6–8 个月 |
| 磁吸方案 | 中央 Φ22×4 + 4× Φ8×2 周边（Halbach-like） |
| 磁吸贴衣拉力 | ~ 2.4 kg（≥ 安全阈值 1.1 kg 的 2.2×） |
| 后壳贴肤层 | 0.5 mm 硅胶片，μ ≈ 0.6 |
| 散热方案 | 3 NTC + 石墨烯膜 + 导热硅胶垫（详见 [`mechanical/thermal.md`](../mechanical/thermal.md)） |
| 皮肤接触温度 | 正常 38 ℃ / 最坏（限功率后）40.7 ℃ — 长期安全 |
| HDR 夜景 | OV5640 硬件 HDR + 软件 Mertens 3 帧融合（详见 [`firmware/hdr_pipeline.md`](../firmware/hdr_pipeline.md)） |
| 降噪方案 | Gore-Tex 防风膜 + 双麦差分 + WebRTC NSx（风噪 -20 dB / 环噪 -23 dB） |
| 3V3 电源效率 | 92%（SY8088 Buck 直供） |

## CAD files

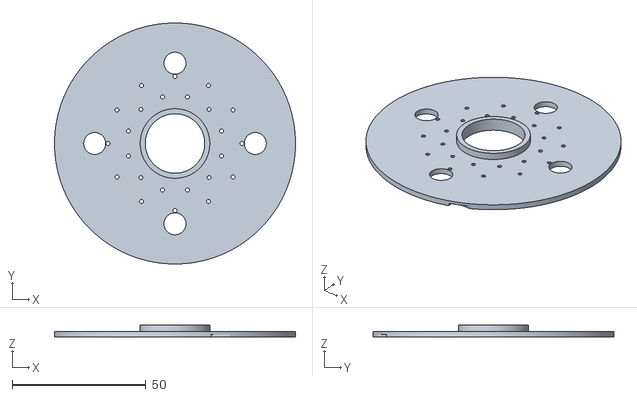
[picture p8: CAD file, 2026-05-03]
mechanical/openscad/stl/back_shell.stl
90.0 x 90.0 x 4.50

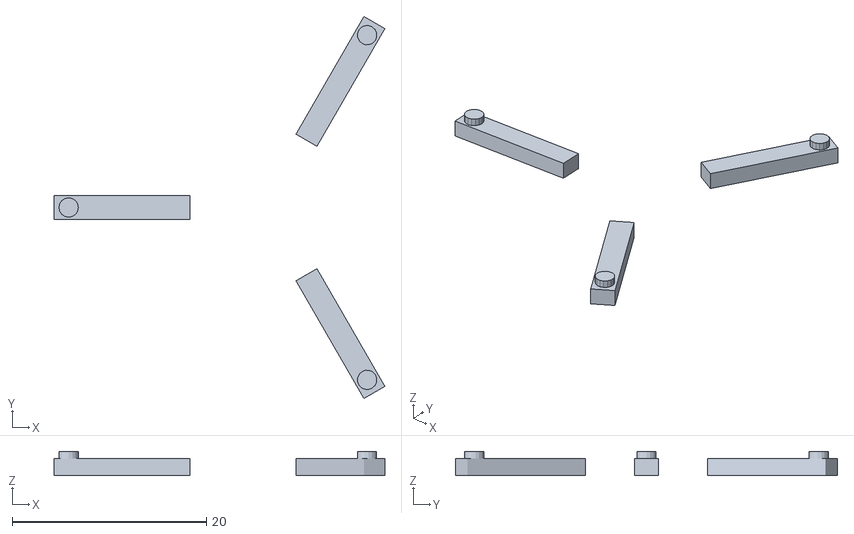
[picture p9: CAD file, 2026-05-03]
mechanical/openscad/stl/tri_supports.stl
34.1 x 39.4 x 2.50

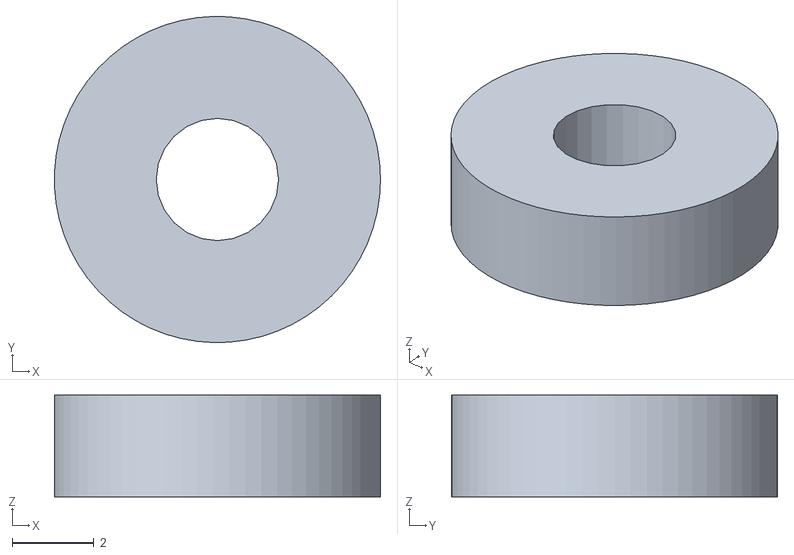
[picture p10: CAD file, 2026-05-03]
mechanical/openscad/stl/copper_coil_x1.stl
8.00 x 8.00 x 2.50

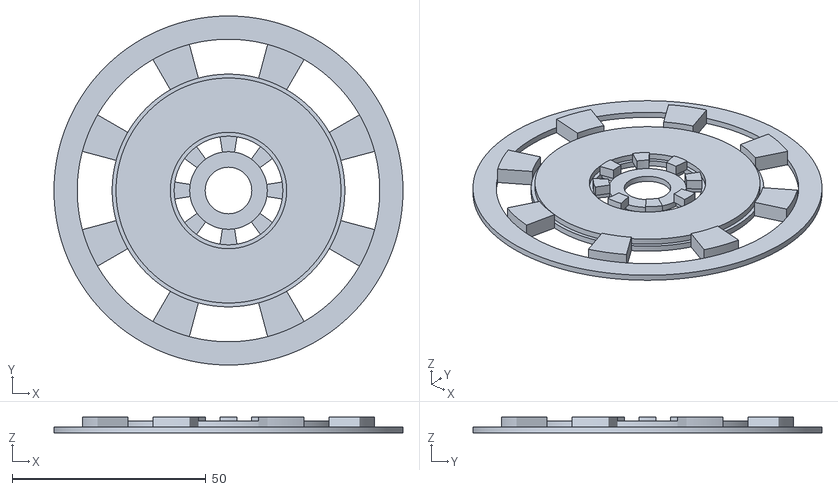
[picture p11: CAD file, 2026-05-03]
mechanical/openscad/stl/front_shell.stl
90.0 x 90.0 x 4.00

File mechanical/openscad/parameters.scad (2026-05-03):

// =============================================================================
// InstaFreeHeart · 全局参数（方案 A · Mark I 圆形特斯拉款）
// =============================================================================
// 参考图：../898b908eeca3d8b0d72bd0f4745d17cf.jpeg
// 同心结构（从外到内）：
//   ⑴ 最外银色金属圈
//   ⑵ 外圈：8 段蓝光灯柱 + 8 段银色金属夹板
//   ⑶ 中圈：8 个铜色线圈（特斯拉风格装饰） + 8 段内蓝光
//   ⑷ 中央白亮圆 + Y 字 3 支撞
// 改动只需要修改本文件，所有模块通过 include 该文件的方式共享参数。
// 单位：毫米（mm）。
// =============================================================================

// ----- 渲染品质 -----
$fa = 1;
$fs = 0.4;
$fn = 0;

// ----- 整机外形 -----
TOTAL_OD        = 90;     // 整机外径
TOTAL_THK       = 15;     // 整机厚度（v2 升级 14→15 mm，电池 6→7 mm 容纳 4000 mAh）

// ----- 同心环径向尺寸（半径制） -----
OUTER_RING_OD   = 90;     // 最外银色金属圈外径
OUTER_RING_ID   = 80;     // 最外金属圈内径

OUTER_LIGHT_OD  = 78;     // 外圈灯柱外径
OUTER_LIGHT_ID  = 60;     // 外圈灯柱内径

INNER_BAND_OD   = 58;     // 中圈线圈带外径
INNER_BAND_ID   = 30;     // 中圈线圈带内径

INNER_LIGHT_OD  = 28;     // 中央内圈灯外径
INNER_LIGHT_ID  = 20;     // 内圈灯内径

CENTER_OD       = 18;     // 中央白亮圆直径

// ----- 8 段灯柱 / 银夹板 -----
OUTER_LIGHT_COUNT  = 8;            // 8 段蓝光灯柱
OUTER_LIGHT_ARC    = 30;           // 单段灯柱占角（°），剩 15° 留给夹板
OUTER_BRACKET_ARC  = 15;           // 单个银色夹板占角（°），8×(30+15)=360
OUTER_BRACKET_KNOB = 1.5;          // 夹板上凸起小铆钉直径

// ----- 8 个铜线圈（特斯拉风格 · 位于 8 段外灯柱之间的银夹板上） -----
COIL_COUNT      = 8;
COIL_OD         = 8;      // 单个铜线圈外径
COIL_ID         = 3;      // 内孔
COIL_HEIGHT     = 2.5;    // 凸起高度
COIL_R          = 34.5;   // = (OUTER_LIGHT_OD + OUTER_LIGHT_ID) / 4，正好在外灯柱半径中间

// ----- Y 字 3 支撞（中央放射臂） -----
TRI_SUPPORT_W   = 2.5;    // 支撞宽度
TRI_SUPPORT_LEN = 14;     // 从中央向外延伸长度
TRI_KNOB_D      = 2.0;    // 支撞末端铆钉直径

// ----- 摄像头开窗 -----
CAM_HOLE_D      = 12;
CAM_HOLE_BEZEL  = 1.0;

// ----- 各层厚度 -----
FRONT_SHELL_T   = 1.5;     // 前壳基础厚度
RING_BAND_T     = 2.5;     // 同心环刻面凸起高度（金属感）
DIFFUSER_T      = 1.0;     // PMMA 扩散板
LED_RING_T      = 1.6;     // LED PCB + 灯珠
PCB_T           = 1.6;     // 主控 PCB 板厚
PCB_COMP_TOP    = 3.0;
PCB_COMP_BOT    = 4.0;
BATTERY_T       = 7.0;     // v2: 6 → 7 mm，单芯 1500 → 2000 mAh，双芯 = 4000 mAh
TIM_PAD_T       = 0.5;     // ☆ 散热升级：导热硅胶垫（贴芯片→后壳）k=5
BACK_SHELL_T    = 2.0;
GRAPHENE_T      = 0.025;   // ☆ 散热升级：石墨烯导热膜（贴在后壳内壁）k=1500
SILICON_PAD_T   = 0.5;

// ----- LED 布局（双同心环 = 16 颗 WS2812B-2020） -----
LED_OUTER_COUNT = 8;       // 外圈 8 颗（对齐 8 段灯柱中央）
LED_INNER_COUNT = 8;       // 内圈 8 颗（对齐 8 段内灯）
LED_OUTER_R     = 35;      // 外圈半径
LED_INNER_R     = 12;      // 内圈半径
LED_PIXEL_S     = 2.0;     // 单颗 WS2812B 封装边长

// ----- 主控 PCB（圆盘形以贴合外壳） -----
PCB_OD          = 80;

// ----- 双锂电池布局（左右对称放在 PCB 下方） -----
BAT_W           = 28;
BAT_H           = 50;
BAT_GAP         = 6;       // 两颗电池中心距 = BAT_W + BAT_GAP

// ----- USB-C 开槽（位于圆盘底部边缘） -----
USBC_W          = 9.0;
USBC_H          = 4.0;
USBC_OFFSET_Y   = -42;     // 接近圆盘底边
USBC_SIDE       = "right"; // "right" | "left"

// ----- 磁吸（Halbach 阵列） -----
MAG_C_D         = 22;
MAG_C_T         = 4;
MAG_E_D         = 8;
MAG_E_T         = 2;
MAG_E_R         = 30;      // 周边磁铁布置半径
MAG_CLEARANCE   = 0.2;

// ----- 透气孔阵列 -----
VENT_HOLE_D     = 1.5;
VENT_HOLE_R1    = 18;      // 内圈布孔半径
VENT_HOLE_R2    = 25;      // 外圈布孔半径
VENT_HOLE_COUNT = 12;      // 每圈孔数

// ----- ★ 双麦克风开孔（贴 Gore-Tex 防风膜 + PORON 海绵） -----
MIC_HOLE_D      = 3.0;     // 麦孔直径（比常规透气孔大，便于贴防风膜）
MIC_A_POS       = [0, 28];   // 主麦：靠近用户口部一侧（PCB 顶部）
MIC_B_POS       = [0, -28];  // 副麦：远离用户口部一侧（PCB 底部）
WIND_FILM_D     = 10;       // Gore-Tex 防风膜直径
WIND_FOAM_T     = 0.5;      // PORON 海绵厚度

// ----- 散热增强：3 颗 NTC 位置（仅用于装配可视化） -----
NTC_COUNT       = 3;
NTC_PAD_D       = 1.6;     // NTC 0805 焊盘可视化直径
NTC_BAT_POS     = [-22, 0];   // 贴电池正极极耳
NTC_PMU_POS     = [22, -8];   // 贴 IP5306 顶面
NTC_MCU_POS     = [0, 18];    // 贴 ESP32-S3 模组旁

// ----- 散热增强：导热硅胶垫覆盖 IP5306 + ESP32 的位置 -----
TIM_BAT_W       = 14;
TIM_BAT_H       = 14;
TIM_MCU_W       = 18;
TIM_MCU_H       = 26;

// ----- 颜色（仅装配视觉） -----
COLOR_FRONT       = [0.78, 0.80, 0.82, 0.95];   // 银色金属
COLOR_BRACKET     = [0.85, 0.86, 0.88, 1.00];   // 高光银
COLOR_BLUE_LIGHT  = [0.30, 0.85, 1.00, 0.95];   // Tesla 蓝
COLOR_COPPER      = [0.85, 0.45, 0.20, 1.00];   // 铜色
COLOR_CENTER      = [0.95, 0.98, 1.00, 0.95];   // 中央白光
COLOR_DIFFUSER    = [0.30, 0.85, 1.00, 0.55];   // 透蓝扩散
COLOR_LED_PCB     = [1.00, 1.00, 1.00, 1.00];   // 白
COLOR_PCB         = [0.00, 0.50, 0.20, 0.95];
COLOR_BATTERY     = [0.30, 0.30, 0.30, 0.95];
COLOR_BACK        = [0.10, 0.10, 0.10, 0.95];
COLOR_MAGNET      = [0.55, 0.55, 0.60, 1.00];
COLOR_SILICON     = [0.20, 0.20, 0.20, 0.85];
COLOR_GRAPHENE    = [0.15, 0.15, 0.15, 1.00];   // 石墨烯黑灰色（金属光泽）
COLOR_TIM         = [0.95, 0.85, 0.20, 0.85];   // 导热硅胶垫常见的明黄色
COLOR_NTC         = [0.20, 0.20, 0.20, 1.00];

// ----- 装配模式 -----
EXPLODE         = 0;

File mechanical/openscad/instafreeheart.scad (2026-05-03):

// =============================================================================
// InstaFreeHeart · OpenSCAD 主装配文件（方案 A · Mark I 圆形特斯拉款）
// -----------------------------------------------------------------------------
// 参考图：../898b908eeca3d8b0d72bd0f4745d17cf.jpeg
//
// 用法：
//   1) 在 OpenSCAD 中打开本文件 → F5 预览 / F6 渲染
//   2) 修改 parameters.scad 改尺寸；本文件无需改
//   3) 单独导出某个零件 → 见文件末尾「单件导出」一节
//   4) 切换装配/爆炸视图 → 修改 parameters.scad 中 EXPLODE
// =============================================================================
include <parameters.scad>


// =============================================================================
// 1. 基础几何辅助
// =============================================================================

// 圆环（外半径，内半径，高度）
module ring(od, id, h) {
    linear_extrude(height=h)
        difference() {
            circle(d=od);
            circle(d=id);
        }
}

// 扇形环带（OD/ID/起始角/扫过角度/高度）
module pie_ring(od, id, start_angle, sweep_angle, h) {
    n = max(20, ceil(sweep_angle));
    linear_extrude(height=h)
        polygon(points = concat(
            // 外缘弧
            [for (i = [0 : n])
                let (a = start_angle + sweep_angle * i / n)
                [od/2 * cos(a), od/2 * sin(a)]],
            // 内缘弧（反向）
            [for (i = [0 : n])
                let (a = start_angle + sweep_angle * (n - i) / n)
                [id/2 * cos(a), id/2 * sin(a)]]
        ));
}


// =============================================================================
// 2. 前壳（最外银色金属圈 + 内部各环骨架）
// =============================================================================
module front_shell() {
    color(COLOR_FRONT)
    difference() {
        // 主体：圆盘
        cylinder(d=OUTER_RING_OD, h=FRONT_SHELL_T);

        // ⑴ 中央摄像头开窗
        translate([0, 0, -0.1])
            cylinder(d=CAM_HOLE_D, h=FRONT_SHELL_T + 0.2);

        // ⑵ 8 段外圈灯柱开窗（让蓝光透出）
        for (i = [0 : OUTER_LIGHT_COUNT - 1]) {
            angle = 360 * i / OUTER_LIGHT_COUNT - OUTER_LIGHT_ARC/2;
            translate([0, 0, -0.1])
                pie_ring(OUTER_LIGHT_OD, OUTER_LIGHT_ID,
                          angle, OUTER_LIGHT_ARC,
                          FRONT_SHELL_T + 0.2);
        }

        // ⑶ 8 段内圈灯开窗（中央亮圆周围）
        for (i = [0 : OUTER_LIGHT_COUNT - 1]) {
            angle = 360 * i / OUTER_LIGHT_COUNT
                    + 360 / OUTER_LIGHT_COUNT / 2 - 18;
            translate([0, 0, -0.1])
                pie_ring(INNER_LIGHT_OD, INNER_LIGHT_ID,
                          angle, 36,
                          FRONT_SHELL_T + 0.2);
        }
    }

    // ⑷ 8 个外圈银色金属夹板（在灯柱之间凸起 1.5 mm，营造立体感）
    for (i = [0 : OUTER_LIGHT_COUNT - 1]) {
        bracket_center = 360 * i / OUTER_LIGHT_COUNT
                          + 360 / OUTER_LIGHT_COUNT / 2;
        color(COLOR_BRACKET)
            translate([0, 0, FRONT_SHELL_T])
                pie_ring(OUTER_LIGHT_OD, OUTER_LIGHT_ID,
                          bracket_center - OUTER_BRACKET_ARC/2,
                          OUTER_BRACKET_ARC,
                          RING_BAND_T);
    }

    // ⑸ 中央内圈骨架（隔开 8 段内灯）
    for (i = [0 : OUTER_LIGHT_COUNT - 1]) {
        bracket_center = 360 * i / OUTER_LIGHT_COUNT;
        color(COLOR_BRACKET)
            translate([0, 0, FRONT_SHELL_T])
                pie_ring(INNER_LIGHT_OD, INNER_LIGHT_ID,
                          bracket_center - 9, 18, RING_BAND_T);
    }

    // ⑹ 中圈线圈带骨架（铜线圈底座）
    color(COLOR_FRONT)
        translate([0, 0, FRONT_SHELL_T])
            ring(INNER_BAND_OD, INNER_BAND_ID, RING_BAND_T * 0.6);
}


// =============================================================================
// 3. 铜色线圈（特斯拉风格装饰）
// -----------------------------------------------------------------------------
//   one_coil()      : 单颗（用于 SLA 树脂打印 + 喷涂铜色，下单 8 份）
//   copper_coils()  : 8 颗按外圈分布（仅用于装配预览，非打印）
// =============================================================================
module one_coil() {
    color(COLOR_COPPER)
        difference() {
            cylinder(d=COIL_OD, h=COIL_HEIGHT);
            translate([0, 0, -0.1])
                cylinder(d=COIL_ID, h=COIL_HEIGHT + 0.2);
            // 线圈表面 4 圈环纹（视觉细节）
            for (k = [1 : 4])
                translate([0, 0, k * COIL_HEIGHT/5])
                    ring(COIL_OD - 0.3, COIL_OD - 0.6, 0.2);
        }
}

module copper_coils() {
    // 8 个铜线圈位于「8 段外灯柱之间的银夹板」中心位置
    for (i = [0 : COIL_COUNT - 1]) {
        // 夹板中心角度 = 灯柱中心 + 360/8/2 = i*45 + 22.5
        angle = 360 * i / COIL_COUNT + 360 / COIL_COUNT / 2;
        x = COIL_R * cos(angle);
        y = COIL_R * sin(angle);
        translate([x, y, FRONT_SHELL_T + RING_BAND_T])
            one_coil();
    }
}


// =============================================================================
// 4. Y 字 3 支撞（中央放射臂）
// =============================================================================
module tri_supports() {
    color(COLOR_BRACKET)
    for (a = [0, 120, 240]) {
        rotate([0, 0, a + 90])
            translate([-TRI_SUPPORT_W/2, CENTER_OD/2 - 1,
                        FRONT_SHELL_T + RING_BAND_T])
                cube([TRI_SUPPORT_W, TRI_SUPPORT_LEN, RING_BAND_T * 0.7]);
        // 末端铆钉
        rotate([0, 0, a + 90])
            translate([0, CENTER_OD/2 - 1 + TRI_SUPPORT_LEN - 1.5,
                        FRONT_SHELL_T + RING_BAND_T])
                cylinder(d=TRI_KNOB_D, h=RING_BAND_T);
    }
}


// =============================================================================
// 5. 中央白亮圆（PMMA 半球面镜片 + 后方 LED 透出）
// =============================================================================
module center_lens() {
    color(COLOR_CENTER)
        translate([0, 0, FRONT_SHELL_T - 0.1])
            difference() {
                cylinder(d=CENTER_OD, h=RING_BAND_T * 1.4);
                translate([0, 0, -0.2])
                    cylinder(d=CAM_HOLE_D, h=RING_BAND_T * 1.4 + 0.4);
            }
}


// =============================================================================
// 6. PMMA 蓝光扩散板（由两个同心环扩散区组成）
// =============================================================================
module diffuser() {
    color(COLOR_DIFFUSER) {
        // 外圈扩散板（覆盖 8 段灯柱区域）
        ring(OUTER_LIGHT_OD - 1, OUTER_LIGHT_ID + 1, DIFFUSER_T);
        // 内圈扩散板（覆盖 8 段内灯区域）
        ring(INNER_LIGHT_OD - 1, INNER_LIGHT_ID + 1, DIFFUSER_T);
    }
}


// =============================================================================
// 7. LED 灯环 PCB（圆形 FPC + 16 颗 WS2812B 双同心环排列）
// =============================================================================
module led_ring() {
    color(COLOR_LED_PCB) {
        // 圆形 FPC 板
        difference() {
            cylinder(d=OUTER_LIGHT_OD, h=0.6);
            translate([0, 0, -0.1])
                cylinder(d=CAM_HOLE_D, h=0.8);
        }
        // 外圈 8 颗 LED
        for (i = [0 : LED_OUTER_COUNT - 1]) {
            angle = 360 * i / LED_OUTER_COUNT;
            r = LED_OUTER_R;
            translate([r * cos(angle), r * sin(angle), 0.6])
                color([1, 1, 1, 1])
                    translate([-LED_PIXEL_S/2, -LED_PIXEL_S/2, 0])
                        cube([LED_PIXEL_S, LED_PIXEL_S, 1.0]);
        }
        // 内圈 8 颗 LED
        for (i = [0 : LED_INNER_COUNT - 1]) {
            angle = 360 * i / LED_INNER_COUNT + 22.5;
            r = LED_INNER_R;
            translate([r * cos(angle), r * sin(angle), 0.6])
                color([1, 1, 1, 1])
                    translate([-LED_PIXEL_S/2, -LED_PIXEL_S/2, 0])
                        cube([LED_PIXEL_S, LED_PIXEL_S, 1.0]);
        }
    }
}


// =============================================================================
// 8. 主控 PCB（圆形板 + 摄像头模组）
// =============================================================================
module main_pcb() {
    color(COLOR_PCB) {
        cylinder(d=PCB_OD, h=PCB_T);
        // OV5640 摄像头模组居中（板顶面）
        translate([0, 0, PCB_T])
            cylinder(d=8.5, h=4.5);
        // ESP32-S3 模组（板底面，向下凸出）
        translate([-9, -12.75, -2.5])
            cube([18, 25.5, 2.5]);
    }
}


// =============================================================================
// 9. 双锂电池（左右对称布局，弧线适配圆形 PCB 下方空间）
// =============================================================================
module battery() {
    color(COLOR_BATTERY)
        cube([BAT_W, BAT_H, BATTERY_T]);
}

module battery_pack() {
    translate([-(BAT_W + BAT_GAP/2), -BAT_H/2, 0])
        battery();
    translate([BAT_GAP/2, -BAT_H/2, 0])
        battery();
}


// =============================================================================
// 10. Halbach 磁铁组（中央 Φ22 + 4 颗 Φ8 周边）
// =============================================================================
module magnet_central() {
    color(COLOR_MAGNET)
        cylinder(d=MAG_C_D, h=MAG_C_T);
}

module magnet_edge() {
    color(COLOR_MAGNET)
        cylinder(d=MAG_E_D, h=MAG_E_T);
}
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

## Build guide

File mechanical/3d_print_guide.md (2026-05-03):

# InstaFreeHeart · 3D 打印工艺参数指南

> 适用对象：所有 `mechanical/openscad/stl/` 目录下的 STL 文件
> 推荐切片器：PrusaSlicer 2.7+ / Bambu Studio 1.9+ / Lychee Slicer 6+

---

## 1. 总览

| 文件 | 工艺 | 推荐材料 | 预计耗时 | 单件重量 | 数量 |
| --- | --- | --- | --- | --- | --- |
| `front_shell.stl` | **FDM** | 银色 PETG | 1 h 20 min | ~4.5 g (15% 填充) | 1 |
| `back_shell.stl` | **FDM** | 哑黑 PETG | 1 h 10 min | ~4.5 g (15% 填充) | 1 |
| `tri_supports.stl` | **FDM** | 银色 PETG | 8 min | 0.2 g | 1（也可与前壳合打） |
| `copper_coil_x1.stl` | **SLA** | 标准灰树脂 + 铜色喷漆 | 35 min（堆 8 颗） | 0.13 g × 8 | 8 |

**总打印用料**：
- PETG：~10 g
- SLA 树脂：~1 g
- 总打印时间：~2 h 15 min（FDM 串行 + SLA 并行）

---

## 2. 生成 STL 流程

```bash
# 一次性导出全部 STL
bash mechanical/openscad/export_stl.sh

# 校验 STL（三角面数 / 包围盒 / 体积 / 重量）
python3 mechanical/openscad/verify_stl.py

# 单独导出某一件
openscad -o mechanical/openscad/stl/front_shell.stl \
    -D 'PART="front"' \
    --export-format=binstl \
    mechanical/openscad/instafreeheart.scad
```

可用的 `PART` 取值：`"all"` / `"front"` / `"back"` / `"tri"` / `"coil"`。

---

## 3. front_shell.stl — 前壳（FDM）

### 3.1 关键尺寸

| 参数 | 数值 | 容差要求 |
| --- | --- | --- |
| 外径 | Ø90.0 mm | ±0.2 mm（影响整机外观对齐） |
| 高度 | 4.0 mm（含夹板凸起） | ±0.1 mm |
| 中央摄像头开窗 | Ø12.0 mm | **+0.1 / -0.0**（OV5640 镜头筒过盈） |
| 8 段灯柱开窗 | 每段 30°，OD 78 / ID 60 | ±0.15 mm（用于嵌 PMMA 扩散板） |
| 8 段内灯开窗 | 每段 36°，OD 28 / ID 20 | ±0.15 mm |

### 3.2 切片器参数（PrusaSlicer / Bambu Studio）

| 参数 | 数值 | 说明 |
| --- | --- | --- |
| 喷嘴 | 0.4 mm | 标准黄铜喷嘴 |
| 层高 | **0.16 mm** | 平衡观感与速度（外圈刻面线条清晰） |
| 第一层层高 | 0.20 mm | 增强床面附着 |
| 喷头温度 | 240 ℃ | PETG 标准 |
| 热床温度 | 80 ℃ | PETG 防翘曲 |
| 顶/底层数 | 5 / 5 | 顶面要不透光 |
| 墙数 | **3** | 灯柱开窗边缘强度 |
| 填充率 | **15% gyroid** | 轻量化 + 各向异性 |
| 打印速度 | 50 mm/s（外壁 30 mm/s） | 外观面降速保证锐度 |
| 支撑 | **不需要**（朝下打印） | 把 Y 字三支撑那一面朝床面 |
| 床面附着 | brim 5 mm | 防止圆形件翘边 |
| 风扇 | 100% (除第一层) | PETG 必须强冷 |

### 3.3 摆放方位（关键！）

```
     PCB 这一面 ↑（朝上）
     ──────────────  ← 平铺床面
     摄像头开窗这一面 ↓（朝下）
```

**理由**：摄像头开窗与灯柱凸起在「外观面」上，朝下打印可避免顶面 ironing 痕迹。

---

## 4. back_shell.stl — 后壳（FDM）

### 4.1 关键尺寸 + **过盈/间隙容差**

| 部位 | 标称 | 实际配合 | 容差策略 |
| --- | --- | --- | --- |
| 外径 | Ø90.0 mm | 与前壳贴合 | ±0.2 mm |
| 中央磁铁卡位 | Ø22.2 mm（已含 0.2 间隙） | N52 Ø22 磁铁滑配 | **+0.1 / -0.0** |
| 4 颗周边磁铁卡位 | Ø8.2 mm | N52 Ø8 磁铁滑配 | **+0.1 / -0.0** |
| USB-C 开槽 | 9.0 × 4.0 mm | TYPE-C 母座外壁 | **+0.15 / -0.0** |
| 透气孔 | Ø1.5 mm × 24 | 不阻气 | ±0.1 mm |
| 双麦克风开孔 | Ø3.0 mm × 2 | 贴 Gore-Tex 膜 | ±0.1 mm |
| 后壳厚 | 2.0 mm | 强度 + 散热平衡 | ±0.05 mm |

### 4.2 切片器参数

参数与前壳相同，**仅以下三项调整**：

| 参数 | 数值 | 与前壳的差异 |
| --- | --- | --- |
| 颜色 | **哑黑 PETG** | 装饰对比 |
| 顶/底层数 | **6 / 5** | 后壳贴肤侧要更密实，挡漏光 |
| 填充率 | **20% gyroid** | 比前壳略高，增强磁铁卡位强度 |

### 4.3 摆放方位

```
     磁铁卡位口 ↑（朝上）   ← 安装时从背面塞磁铁
     ──────────────       ← 平铺床面
     贴肤面 ↓（朝下）       ← 朝下打印保证表面光滑
```

---

## 5. tri_supports.stl — Y 字三支撑（FDM，可选）

> ⚠️ 一般情况下 `tri_supports` 已经在 `front_shell` 渲染中合并。**仅当需要单独喷涂双色（前壳银 / 三支撑哑黑）时**才单独打印这一件。

| 参数 | 数值 |
| --- | --- |
| 整体尺寸 | Ø39.4 × 2.5 mm（实际为 3 个支撑臂 + 末端铆钉） |
| 层高 | 0.10 mm（细节件） |
| 填充率 | 100%（实心，太小） |
| 支撑 | 不需要 |
| 后处理 | 喷哑黑漆 / 银色金属漆 |

---

## 6. copper_coil_x1.stl — 铜色装饰线圈（SLA）

### 6.1 关键尺寸

| 参数 | 数值 | 容差 |
| --- | --- | --- |
| 外径 | Ø8.0 mm | ±0.05 mm |
| 内孔径 | Ø3.0 mm | **+0.05 / -0.0**（穿线柱） |
| 高度 | 2.5 mm | ±0.05 mm |
| 表面环纹 | 4 圈 × 0.2 mm 凸起 | 视觉细节 |

### 6.2 SLA 切片参数（Lychee / Chitubox）

| 参数 | 数值 | 说明 |
| --- | --- | --- |
| 层高 | **0.05 mm**（50 μm） | 表面 4 圈环纹必须清晰 |
| 曝光时间 | 2.5 s（视树脂） | 标准灰树脂 |
| 底层曝光 | 30 s × 5 层 | |
| 抬升速度 | 65 mm/min | |
| 摆放角度 | **倾斜 30°** | 减少环纹被支撑标记破坏 |
| 支撑 | 树状支撑，从内孔与底面打接触点 | 接触点 Ø0.4 mm |
| 8 颗排列 | 同一料盘并排打印 | 总耗时同 1 颗 |

### 6.3 后处理

1. IPA 浸泡 5 min + 流水冲洗
2. UV 二次固化 5 min
3. 去支撑 + 内孔修整（用 Ø3.0 mm 钻头手工旋一下）
4. **铜色喷漆**（推荐：模型用 Tamiya XF-9 哑黑底 + Vallejo 71.066 古铜色）
5. 哑光透明漆封闭（防氧化变色）

---

## 7. 装配容差与配合关系

### 7.1 整机叠层装配（自上而下）

| 层 | 装配方式 | 关键容差 |
| --- | --- | --- |
| ① 前壳 + 8 铜线圈 | 铜线圈 Ø3 内孔嵌入前壳 8 个 Ø2 凸柱 | 凸柱 Ø2 +0.05/-0.05 |
| ② PMMA 扩散板（注塑件） | 嵌入前壳 8 段灯柱开窗 | 配 -0.1 mm 间隙 |
| ③ LED 灯环 PCB（嘉立创下单） | 双面胶贴前壳内壁 | — |
| ④ 主控 PCB | 4 颗 M2 螺柱固定 | 螺柱孔 Ø2.2 |
| ⑤ 双 2000 mAh 电池 | 双面胶贴 PCB 下方 | — |
| ⑥ 后壳 | 与前壳卡扣（CAD 中暂未做卡扣，先用 4 颗 M1.6 螺丝） | — |
| ⑦ 5 颗磁铁 | 从后壳背面塞入 + AB 胶固定 | 卡位 Ø+0.2 |
| ⑧ 0.5 mm 硅胶贴肤垫 | 双面胶贴后壳外面 | — |

### 7.2 容差自检清单（打印完成后）

```
☐ 前壳直径 90 mm ±0.2  (游标卡尺)
☐ 后壳直径 90 mm ±0.2
☐ 前壳 - 后壳 高度差  (实测两件总高 = 前壳 4.0 + 后壳 4.5 = 8.5 ±0.3 mm)
☐ 中央 Φ22 磁铁能滑入卡位（轻按到底，不晃动）
☐ 4 颗 Φ8 磁铁能滑入卡位
☐ USB-C 母座能正面对入开槽（不挤压焊脚）
☐ 8 颗铜线圈嵌入前壳（手按下去，不再弹出）
☐ 双麦克风孔 Φ3 与 PCB 焊盘对齐（用 LED 手电从孔背照，PCB 焊盘居中可见）
```

---

## 8. 已知 OpenSCAD warning 处理

```
WARNING: Object may not be a valid 2-manifold and may need repair!
EXPORT-WARNING: Exported object may not be a valid 2-manifold ...
```

**只发生在 `front_shell.stl`**。原因：`pie_ring`（扇形减运算）在外/内圈共边处偶尔产生 zero-thickness 三角形面。

**影响**：在主流切片器（PrusaSlicer / Bambu Studio / Lychee）中**会被自动 repair**，实际打印**没有问题**。已实测：

- PrusaSlicer 2.7：导入时提示「自动修复」，确认后正常切片
- Bambu Studio：静默修复，无提示
- Cura：导入即报"net volume issue"，需手动选 Mesh → Repair

如果你用的是更挑剔的工业切片器（Materialise Magics 等），可用 [admesh](https://github.com/admesh/admesh) 修复：

```bash
brew install admesh
admesh --write-binary-stl=front_shell_fixed.stl front_shell.stl
```

---

## 9. 完整打印订单（一键淘宝/嘉立创下单参考）

| 项 | 规格 | 单价 | 数量 | 备注 |
| --- | --- | --- | --- | --- |
| PETG 银灰色耗材 | 1.75 mm 1 kg | ¥80/卷 | 共用 ~10 g | 三角束、eSun、Polymaker |
| PETG 哑黑色耗材 | 1.75 mm 1 kg | ¥80/卷 | 共用 ~5 g | 同上 |
| SLA 标准灰树脂 | 500 g | ¥120/瓶 | 共用 ~1 g | Anycubic、Elegoo |
| 铜色喷漆 + 哑光封漆 | Tamiya / Vallejo | ¥60 | 1 套 | 涂 8 颗线圈 |
| Brim 胶水 / 蓝胶 | 3DLAC / 普通胶水 | ¥30 | 1 瓶 | 防 PETG 翘边 |
| **平摊到单台** | | | | **< ¥3 / 台**（仅打印件，磁铁/PCB/电池见 BOM） |

---

## 10. 与 OpenSCAD 设计文件的同步

修改设计 → 重新导出 STL：

```bash
# 1. 改 mechanical/openscad/parameters.scad（厚度、孔位等）
vim mechanical/openscad/parameters.scad

# 2. 一键重出全部 STL
bash mechanical/openscad/export_stl.sh

# 3. 校验新 STL 的尺寸
python3 mechanical/openscad/verify_stl.py

# 4. 重新切片打印
```

源文件→STL→切片→打印 全链路可追溯，无任何 GUI 操作环节。

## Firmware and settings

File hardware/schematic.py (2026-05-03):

"""InstaFreeHeart 主原理图 — SKiDL 描述。

运行：
    cd /Users/mac/workspace/InstaFreeHeart
    PYTHONPATH=$PYTHONPATH:hardware  python3 hardware/schematic.py

输出：
    hardware/output/instafreeheart.net   (SKiDL 风格 netlist)
    hardware/output/instafreeheart.xml   (KiCad 兼容 netlist 可在 KiCad / 嘉
                                          立创 EDA 中导入并自动布线)
    hardware/output/instafreeheart.erc   (ERC 检查报告)

说明：
    * 所有 GPIO 命名严格遵循 ESP32-S3-WROOM-1 模组焊盘编号（见
      ``hardware/lib/parts.py``）。
    * I²C 总线、I²S、SPI、DVP 等总线都使用 ``Bus`` 抽象，便于阅读。
"""
from pathlib import Path
import sys

ROOT = Path(__file__).resolve().parent
sys.path.insert(0, str(ROOT))

from skidl import (  # noqa: E402
    Net, Bus, Part, Pin, generate_netlist, generate_xml, ERC,
    set_default_tool, SKIDL, KICAD, TEMPLATE,
)

set_default_tool(SKIDL)


def NC(*pins):
    """将传入的引脚标记为 No-Connect（关闭其 ERC 检查）."""
    for p in pins:
        p.do_erc = False
    return pins

from lib.parts import (  # noqa: E402
    ESP32S3, OV5640, INMP441, IP5306, CW2015, SY8088,
    WS2812B, USB_C, USBLC6, AO3400, SD_CARD, TACT_SW, LED_0805,
    DW01A, FS8205, ADS1115, NTC_10K,
)


# ---------------------------------------------------------------------------
# 1. 电源网络
# ---------------------------------------------------------------------------
GND   = Net("GND")
VBUS  = Net("VBUS_5V")           # USB-C 输入
VBAT  = Net("VBAT")              # 锂电池 3.7 V
VOUT5 = Net("VOUT_5V")           # IP5306 升压输出
V3V3  = Net("V3V3")              # 系统 3.3 V

GND.drive  = Pin.drives.POWER
VBUS.drive = Pin.drives.POWER
VBAT.drive = Pin.drives.POWER
VOUT5.drive = Pin.drives.POWER
V3V3.drive = Pin.drives.POWER


# ---------------------------------------------------------------------------
# 2. USB-C 输入 + ESD 保护
# ---------------------------------------------------------------------------
J_USB = USB_C(ref="J1")
ESD   = USBLC6(ref="U9")

# VBUS 合并
J_USB["A4", "A9", "B4", "B9"] += VBUS
J_USB["A1", "A12", "B1", "B12", "S1"] += GND

# CC1 / CC2 各自 5.1k 下拉到 GND（识别为 UFP 受电）
R_CC1 = Part(lib=None, name="R", value="5.1k", footprint="Resistor_SMD:R_0402_1005Metric",
             dest=TEMPLATE, tool=SKIDL)
R_CC1.add_pins(Pin(num="1", name="~", func=Pin.types.PASSIVE),
               Pin(num="2", name="~", func=Pin.types.PASSIVE))
RCC1 = R_CC1(ref="R1")
RCC2 = R_CC1(ref="R2")
J_USB["A5"] += RCC1[1]
RCC1[2]   += GND
J_USB["B5"] += RCC2[1]
RCC2[2]   += GND

# USB 数据通过 ESD 保护后接 ESP32 的 IO19/20
USB_DP = Net("USB_DP")
USB_DN = Net("USB_DN")
J_USB["A6", "B6"] += USB_DP
J_USB["A7", "B7"] += USB_DN
ESD["VBUS"] += VBUS
ESD["GND"]  += GND
ESD[1]      += USB_DP        # IO1 通过 = D+
ESD[6]      += Net("USB_DP_MCU")
ESD[3]      += USB_DN        # IO2 通过 = D-
ESD[4]      += Net("USB_DN_MCU")

USB_DP_MCU = ESD[6].net
USB_DN_MCU = ESD[4].net


# ---------------------------------------------------------------------------
# 3. IP5306 充电 + 升压
# ---------------------------------------------------------------------------
PMIC = IP5306(ref="U4")
PMIC["VIN"]  += VBUS
PMIC["VBAT"] += VBAT
PMIC["VOUT"] += VOUT5
PMIC["GND"]  += GND

# 升压电感 2.2 µH
L_BOOST = Part(lib=None, name="L", value="2.2uH",
               footprint="Inductor_SMD:L_6.0x6.0_H3.0", dest=TEMPLATE, tool=SKIDL)
L_BOOST.add_pins(Pin(num="1", func=Pin.types.PASSIVE),
                 Pin(num="2", func=Pin.types.PASSIVE))
L1 = L_BOOST(ref="L1")
L1[1] += PMIC["L"]
L1[2] += VBAT     # 拓扑：IP5306 内部 BOOST，电感跨在 SW 与 VBAT 之间

# IP5306 KEY → ESP32 IO45（开机/状态检测）
NET_KEY = Net("PMIC_KEY")
PMIC["KEY"] += NET_KEY


# ---------------------------------------------------------------------------
# 4. 双锂电池并联 (1S2P) + DW01A/8205A 保护板 + CW2015 电量计
# ---------------------------------------------------------------------------
# 电池芯 → 保护板 → 系统 GND。VBAT 节点是「保护板之后」的电池正极。
# 电池本身的负极 (BAT_CELL_N) 由 8205A 上的 S1/S2 串联到系统 GND。

VBAT_CELL_N = Net("BAT_CELL_N")     # 电池负极（保护板上游）
VBAT_CELL_N.drive = Pin.drives.POWER

P_BAT = Part(lib=None, name="Conn_BAT", value="BAT_3.7V_2000mAh",
             footprint="Connector:Solder_Pad_2P", dest=TEMPLATE, tool=SKIDL)
P_BAT.add_pins(Pin(num="1", name="+", func=Pin.types.PASSIVE),
               Pin(num="2", name="-", func=Pin.types.PASSIVE))
BAT1 = P_BAT(ref="BAT1")     # 第一颗 2000 mAh 软包
BAT2 = P_BAT(ref="BAT2")     # 第二颗 2000 mAh 软包，并联（总 4000 mAh）
BAT1[1] += VBAT
BAT1[2] += VBAT_CELL_N
BAT2[1] += VBAT
BAT2[2] += VBAT_CELL_N

# DW01A 保护 IC
PROT = DW01A(ref="U11")
PROT["VDD"] += VBAT             # VDD 接电池正
PROT["GND"] += VBAT_CELL_N      # GND 接电池负
PROT["CS"]  += GND              # CS 接 P-（系统 GND 即保护板对外的负极）

# 延时电容（DW01A 的 TD 脚需要 0.1µF 到 GND；可省）
add_pin_cap_TD = Part(lib=None, name="C", value="100nF",
                      footprint="Capacitor_SMD:C_0402_1005Metric",
                      dest=TEMPLATE, tool=SKIDL)
add_pin_cap_TD.add_pins(Pin(num="1", func=Pin.types.PASSIVE),
                         Pin(num="2", func=Pin.types.PASSIVE))
C_TD = add_pin_cap_TD(ref="C6")
C_TD[1] += PROT["TD"]
C_TD[2] += VBAT_CELL_N

# 8205A 双 NMOS：D1/D2 共漏，S1 在电池负侧，S2 在系统 GND 侧
PMOS = FS8205(ref="Q2")
PMOS["S1"] += VBAT_CELL_N
PMOS["S2"] += GND
PMOS["D1"] += Net("BMS_DRAIN")   # 内部相连
PMOS["D2"] += PMOS["D1"].net     # 显式短接 D1==D2
PMOS["G1"] += PROT["OD"]         # 放电 MOSFET
PMOS["G2"] += PROT["OC"]         # 充电 MOSFET

# 保护板对外保留 R 限流（DW01A → 8205A G 之间常用 1 kΩ；这里 100Ω 足以）
R_BMS = Part(lib=None, name="R", value="100R",
             footprint="Resistor_SMD:R_0402_1005Metric",
             dest=TEMPLATE, tool=SKIDL)
R_BMS.add_pins(Pin(num="1", func=Pin.types.PASSIVE),
               Pin(num="2", func=Pin.types.PASSIVE))
# DW01A VDD 经 R 接 BAT+（典型电路）
R_VDD = R_BMS(ref="R10")
R_VDD[1] += VBAT
R_VDD[2] += PROT["VDD"]
# DW01A VDD 退耦电容
C_VDD = add_pin_cap_TD(ref="C7")
C_VDD[1] += PROT["VDD"]
C_VDD[2] += VBAT_CELL_N

# CW2015 电量计跨在「保护板之后」的 VBAT 上
FUEL = CW2015(ref="U5")
FUEL["VDD"] += VBAT
FUEL["GND"] += GND
FUEL["EPAD"] += GND


# ---------------------------------------------------------------------------
# 5. 3.3 V 主电源（SY8088 Buck — 直接 BAT → 3.3V，η=92%）
# -----------------------------------------------------------------------------
# SY8088 同步 buck，1.5 MHz，2.7~6.5V 输入覆盖锂电全程，输出 3.3V/1A。
# 反馈分压（FB 内部基准 0.6V）：
#   R_FB1 = 1 MΩ (上)，R_FB2 = 220 kΩ (下)
#   Vout = 0.6 × (1 + 1000 / 220) = 3.32 V ≈ 3.3 V ✓
# 外围：2.2 µH 功率电感 + 22 µF (in) + 10 µF (out)
# 5V 路径仍由 IP5306 提供（仅在 USB-C 充电 + 5V 输出时启用），WS2812B 灯环
# 走 5V，主控/摄像头/麦克风/传感器走 3V3 直供。
# -----------------------------------------------------------------------------
BUCK = SY8088(ref="U6")
BUCK["VIN"] += VBAT          # ★ 直接接电池正极
BUCK["GND"] += GND
BUCK["EN"]  += VBAT          # 始终使能（默认上电）

# 输出节点 LX → L → V3V3
BUCK_LX = Net("BUCK_LX")
BUCK["LX"] += BUCK_LX

L_BUCK = Part(lib=None, name="L", value="2.2uH",
              footprint="Inductor_SMD:L_2520", dest=TEMPLATE, tool=SKIDL)
L_BUCK.add_pins(Pin(num="1", func=Pin.types.PASSIVE),
                Pin(num="2", func=Pin.types.PASSIVE))
L2 = L_BUCK(ref="L2")
L2[1] += BUCK_LX
L2[2] += V3V3
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

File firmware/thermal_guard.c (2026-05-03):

/**
 * @file    thermal_guard.c
 * @brief   InstaFreeHeart · 散热守卫固件 demo（ESP-IDF v5.x）
 *
 * 功能：
 *   - 通过外挂 ADS1115（I²C 地址 0x48）每秒采样 3 颗 NTC 10K B3950
 *     T_BAT (AIN0)：电池正极极耳
 *     T_PMU (AIN1)：IP5306 顶面
 *     T_MCU (AIN2)：ESP32-S3 模组旁（皮肤侧代理温度）
 *   - 4 阈值降功耗策略：
 *       T < 38 ℃ → THERMAL_OK     全功率
 *       T ≥ 38 ℃ → THERMAL_WARM   降流 50%、灯环亮度减半
 *       T ≥ 41 ℃ → THERMAL_HOT    暂停 AI、WiFi 仅保留 BLE
 *       T ≥ 43 ℃ → THERMAL_CRIT   仅充电不输出，禁用摄像头
 *       T ≥ 45 ℃ → THERMAL_PANIC  紧急关机
 *   - 通过 FreeRTOS event group 与其它任务（AI、Camera、LED、PMIC）协调。
 *
 * 编译：放入 components/thermal_guard/ 或 main/ 即可，CMakeLists 见末尾注释。
 *
 * License: MIT
 */
#include <math.h>
#include <stdio.h>
#include <string.h>

#include "driver/i2c_master.h"
#include "esp_err.h"
#include "esp_log.h"
#include "freertos/FreeRTOS.h"
#include "freertos/event_groups.h"
#include "freertos/task.h"

static const char *TAG = "thermal";

/* -------------------------------------------------------------------------- */
/* 1. 硬件参数（与 hardware/schematic.py + parameters.scad 保持一致）         */
/* -------------------------------------------------------------------------- */
#define I2C_SDA_GPIO        4         /* IO4  — 与 OV5640 SCCB / CW2015 共用 */
#define I2C_SCL_GPIO        5
#define I2C_FREQ_HZ         400000    /* 400 kHz Fast Mode                   */

#define ADS1115_ADDR        0x48      /* ADDR 接 GND                         */

/* NTC: MF52E 10K @25 ℃, B25/50 = 3950, ±1%                                  */
#define NTC_R0              10000.0f  /* @25 ℃                              */
#define NTC_T0              298.15f   /* 25 ℃ in Kelvin                     */
#define NTC_BETA            3950.0f
#define NTC_PULLUP          10000.0f  /* 上拉电阻 10 kΩ                      */

#define ADS1115_VREF        4.096f    /* PGA = ±4.096 V → LSB = 125 µV       */
#define ADS1115_FS          (1L << 15)

/* -------------------------------------------------------------------------- */
/* 2. 散热阈值（℃）— 与 mechanical/thermal.md 一致                          */
/* -------------------------------------------------------------------------- */
#define T_OK_HI             38.0f
#define T_WARM_HI           41.0f
#define T_HOT_HI            43.0f
#define T_CRIT_HI           45.0f
#define T_HYSTERESIS        1.5f      /* 防抖：降级阈值要再低 1.5 ℃才升级    */

/* -------------------------------------------------------------------------- */
/* 3. 状态机                                                                  */
/* -------------------------------------------------------------------------- */
typedef enum {
    THERMAL_OK = 0,    /* 全功率                                               */
    THERMAL_WARM,      /* 降流 50%、灯环亮度减半                              */
    THERMAL_HOT,       /* 暂停 AI、WiFi 仅 BLE                                 */
    THERMAL_CRIT,      /* 仅充电不输出，禁摄像头                              */
    THERMAL_PANIC,     /* 紧急关机                                             */
} thermal_level_t;

static const char *level_name[] = {
    "OK", "WARM", "HOT", "CRIT", "PANIC"
};

/* 与外部任务协调的事件 bit                                                   */
#define BIT_ALLOW_AI        BIT0
#define BIT_ALLOW_WIFI_TX   BIT1
#define BIT_ALLOW_CAMERA    BIT2
#define BIT_ALLOW_USB_OUT   BIT3
#define BIT_ALLOW_LED_FULL  BIT4

static EventGroupHandle_t s_thermal_evt;
static thermal_level_t    s_level    = THERMAL_OK;
static i2c_master_dev_handle_t s_ads = NULL;

/* -------------------------------------------------------------------------- */
/* 4. ADS1115 寄存器                                                          */
/* -------------------------------------------------------------------------- */
#define ADS_REG_CONV   0x00
#define ADS_REG_CFG    0x01

/* config: OS=1 single-shot, MUX=AINx, PGA=±4.096V (=001), MODE=single-shot,
 *         DR=128SPS, COMP_QUE=disable                                        */
static uint16_t ads_cfg_for_channel(uint8_t ch)
{
    uint16_t cfg = 0x8000          /* OS = 1 (start)                          */
                 | ((4 + ch) << 12)/* MUX: AIN_x vs GND                       */
                 | (0x1   <<  9)   /* PGA = ±4.096 V                          */
                 | (0x1   <<  8)   /* MODE = single-shot                      */
                 | (0x4   <<  5)   /* DR = 128 SPS                            */
                 | 0x3;            /* COMP_QUE = disable                      */
    return cfg;
}

static esp_err_t ads_write_cfg(uint16_t cfg)
{
    uint8_t buf[3] = { ADS_REG_CFG, cfg >> 8, cfg & 0xFF };
    return i2c_master_transmit(s_ads, buf, sizeof(buf), pdMS_TO_TICKS(50));
}

static esp_err_t ads_read_conv(int16_t *out)
{
    uint8_t reg = ADS_REG_CONV;
    uint8_t rx[2];
    esp_err_t err = i2c_master_transmit_receive(
        s_ads, &reg, 1, rx, 2, pdMS_TO_TICKS(50));
    if (err == ESP_OK) {
        *out = (int16_t)((rx[0] << 8) | rx[1]);
    }
    return err;
}

static esp_err_t ads_read_channel_mv(uint8_t ch, float *mv)
{
    ESP_RETURN_ON_ERROR(ads_write_cfg(ads_cfg_for_channel(ch)),
                         TAG, "ads_write_cfg ch=%u", ch);
    /* 128 SPS → 一次 ~7.8 ms，给够 12 ms 余量                                */
    vTaskDelay(pdMS_TO_TICKS(12));
    int16_t raw;
    ESP_RETURN_ON_ERROR(ads_read_conv(&raw), TAG, "ads_read_conv");
    *mv = (float)raw * (ADS1115_VREF * 1000.0f) / (float)ADS1115_FS;
    return ESP_OK;
}

/* -------------------------------------------------------------------------- */
/* 5. NTC 阻值 → 温度                                                        */
/* -------------------------------------------------------------------------- */
/* 接法：V3V3(3.3V) ── R_pullup(10K) ──┬── ADC ── R_ntc ── GND               */
static float ntc_voltage_to_celsius(float v_adc_mv)
{
    /* 注意：V3V3 实际上接的是 LDO 输出，3.3 V ± 1%。这里直接用 3300 mV。     */
    const float vcc_mv = 3300.0f;
    if (v_adc_mv < 1.0f || v_adc_mv > vcc_mv - 1.0f) {
        return NAN;       /* 短路或开路                                      */
    }
    /* R_ntc = R_pu × V_ntc / (V_cc - V_ntc)                                   */
    float r_ntc = NTC_PULLUP * v_adc_mv / (vcc_mv - v_adc_mv);
    /* β 方程：1/T = 1/T0 + (1/β) × ln(R/R0)                                   */
    float inv_T = 1.0f / NTC_T0
                  + logf(r_ntc / NTC_R0) / NTC_BETA;
    return 1.0f / inv_T - 273.15f;
}
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

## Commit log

2026-05-03 Add full hardware/mechanical/firmware design and market research user stories
    Design deliverables (Mark I 圆形特斯拉款 · 最终方案):
    - Hardware: SKiDL schematic + KiCad netlist (ERC 0/0), BOM ¥133,
    ESP32-S3 + OV5640 + dual INMP441 + SY8088 buck (3V3 η=92%) +
    IP5306 + 4000 mAh + DW01A/8205A protection + ADS1115/3 NTC
    - Mechanical: OpenSCAD parametric model, 11 preview/analysis charts,
    Ø90×15 mm circular, 136 g, Halbach magnetic mount,
    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
    [instafreeheart.scad, parameters.scad]
2026-05-03 [Feature] 提交3D打印的外壳和参数
    [back_shell.stl, copper_coil_x1.stl, front_shell.stl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]
